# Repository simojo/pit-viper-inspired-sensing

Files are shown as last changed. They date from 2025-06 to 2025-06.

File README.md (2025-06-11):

# Pit Viper-Inspired Integration of Thermal and Visual Sensing

This project contains the source code, design files, and run data for our
project that integrates thermal and visual sensing.

[Project Video](https://www.youtube.com/watch?v=YbGg3W7sRKU)

```
Authors (all credited equally):

Julianne Attai         <julianne.attai at colorado dot edu>
Simon Jones            <simon.jones-1 at colorado dot edu>
Tanmay Dharmaji Mhatre <tanmay.mhatre at colorado dot edu>
Saravana Kumar Prakash <sako6004 at colorado dot edu>
```

## Directory Structure

```sh
.
├── apriltag . . . . . . . . . apriltag source code
├── data . . . . . . . . . . . cad models and data from runs
│  ├── mechanical-data
│  └── runs
├── sanity-examples  . . . . . minimal working examples for our own sanity
│  ├── thermal-sensing
│  ├── camera_test.py
│  ├── motor_test.py
│  ├── picam2_array_test.py
│  └── picamera-test.py
├── src  . . . . . . . . . . . main source code
│  └── main.py
├── README.md
├── requirements.txt . . . . . libraries used in source code
└── setup.sh . . . . . . . . . setup script for RPi4
```

## How to run

To set up this project, first source `setup.sh` on a Raspberry Pi 4 image running
Bookworm or later.

```sh
. setup.sh
```

This will take care of initializing the venv and installing system packages.

Next, install the packages from `requirements.txt`:

```sh
pip install -r requirements.txt
```

Finally, run the main source code, using `-d` for debug mode, and `-ld` for data
logging mode. You can optionally disable either thermal or visual sensing by
using `--visual-only` and `--thermal-only` respectively. By default, both
sensing modalities are in use.

```sh
python3 src/main.py [-d] [-ld] [--visual-only] [--thermal-only]
```

## For reference

* https://www.circuitstoday.com/arduino-nano-tutorial-pinout-schematics
* https://learn.sparkfun.com/tutorials/tb6612fng-hookup-guide/all#hardware-setup

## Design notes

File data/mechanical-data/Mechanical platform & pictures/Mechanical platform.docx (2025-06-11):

Mechanical platform

The authors’ main goal from a mechanical perspective is to make room for all the electronic parts, including the Raspberry Pi, breadboard, camera, thermal sensors, motors, batteries, wiring, etc. To ensure that motors and sensors don't wobble while operating, the mechanical housing should also have specific design elements.

1)Concept generation

Our authors developed the design below during preliminary conversations, with the electronic components on the top and bottom base plates intended to be made of acrylic. The writers have also decided to use the trike's motorized front wheels and driven rear wheels for propulsion. For the robot's turning, the differential drive concept was selected.

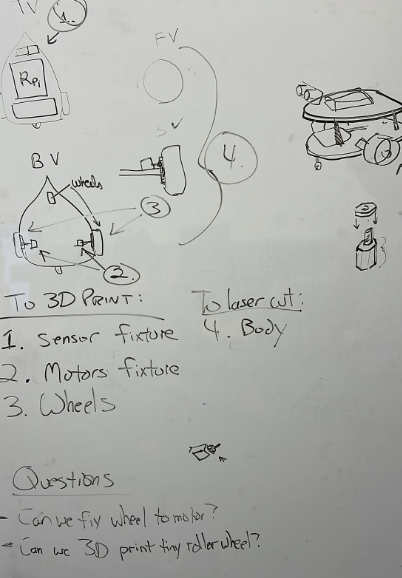
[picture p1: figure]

2) Design iterations

i) Initial design: A CAD model that replicated the idea was created by designers. A table-like framework was all that was originally intended to house sensors at the top and other electrical components that would be packaged below the base.

2) Final design: A snake-head structure was created following multiple forums, as seen below. There is adequate room for sensors at the top that resemble the snake's eyes thanks to this snake-inspired design. Both housings' front sections are sufficiently shaped to avoid obstructing the sensor's field of vision.

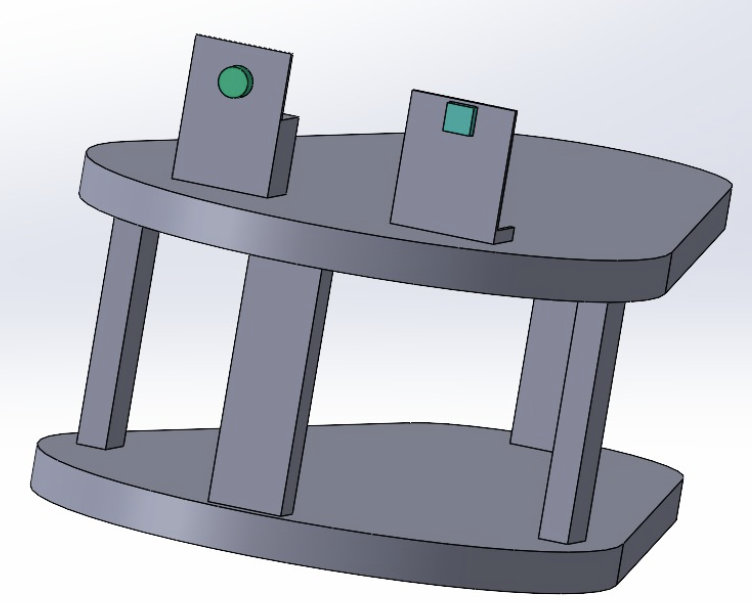
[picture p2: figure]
A drawing of a table
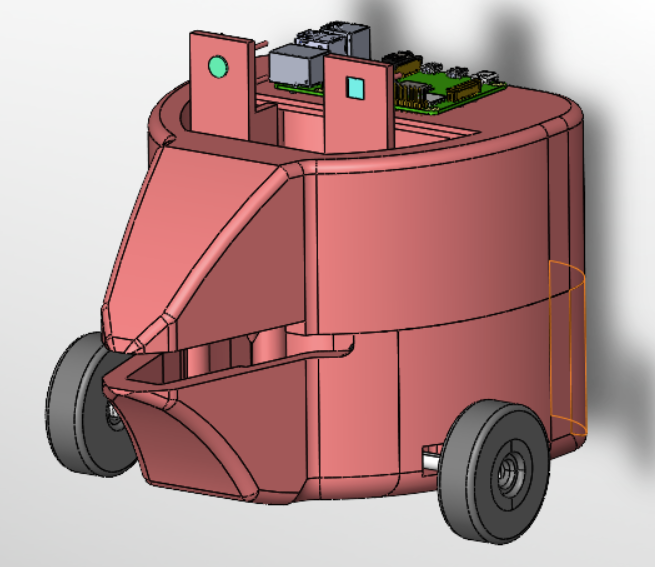
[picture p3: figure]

Final design

Initial design

Manufacturing failures

The body and wheels were created by the writers using 3D printing technology. The outputs were not what was anticipated because of the design's robustness. The body designs were divided into multiple pieces and intended to be joined using the projections and holes method, based on the lessons learned about designing quickly for manufacturing (3D printing). Following a difficult post-printing procedure that resulted in assembly features breaking, the bodies were assembled using Velcro and glue. Velcro is specifically employed to make assembly/disassembly feasible in the event that electronics need to be updated.

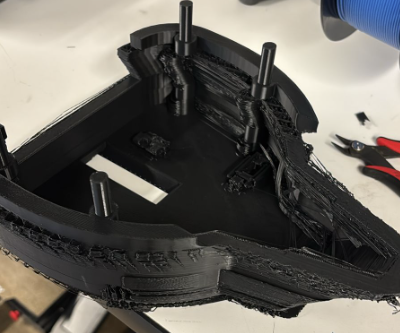
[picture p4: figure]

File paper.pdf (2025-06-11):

# Pit Viper-Inspired Integration of Infrared and Visual Sensing

Julianne Attai∗

, Simon Jones†

, Tanmay Dharmaji Mhatre‡

, Saravana Kumar Prakash§
∗†Robotics Program, University of Colorado Boulder, Boulder, CO, USA ‡§Paul M. Rady Department of Mechanical Engineering, University of Colorado Boulder, Boulder, CO, USA
∗

julianne.attai@colorado.edu, †

simon.jones-1@colorado.edu, ‡

tanmay.mhatre@colorado.edu, § sako6004@colorado.edu

Abstract—Pit vipers leverage both infrared (IR) and vision for hunting. Each sensing modality can function independently but operate more effectively together, motivating the hypothesis that combining and IR and vision will out-perform singlesensing approaches in navigation and prey detection. To test this underlying hypothesis, a robot with dual-sensing capabilities has been designed to integrate information from a Adafruit MLX90640 IR Thermal Camera Breakout - 55 Degree and Raspberry Pi Camera Module 2 and steer the robot accurately towards a target. Thermal sensing performed the best, having the shortest time to reach (TTR) to the target, and the lowest heading angle variance across trials. Visual sensing performed the worst, having the largest variance in heading angles and the longest TTR. Dual sensing had the least variance in heading angle, but did not outperform thermal sensing alone in terms of TTR. The results of this project highlight the integral role IR sensing plays in target tracking accurately during predator-prey interactions.
Index Terms—Infrared Vision, Camera Vision, Pit Vipers.
I. INTRODUCTION
Pit Vipers are ferocious predators that are able to accurately strike their prey, even in darkness. These animals leverage infrared vision, through pit organs rich in heat-sensitive nerve fibers, while hunting to track the radiation emitted by their target. They also use many visual cues during hunting, particularly for navigation and landmark recognition. Both sensing modalities are integral in achieving high predatory performance.
In this report, two sensing modalities, infrared and visual sensing, are integrated to navigate towards a target or prey. In order to implement this, the authors built a mechanical platform that can be steered through differential drive. A Raspberry Pi Camera Module 2 is used to collect visual data, while a Adafruit MLX90640 IR Thermal Camera Breakout
- 55 Degree is used to collect thermal data. This data is processed to identify the distance from target and the desired heading angle to steer towards the target.
In this report, the main contributions of the project are outlined as follows:
- Designing a snake-inspired mechanical platform for IR and vision based steering
- Developing an algorithm to process thermal images and identify the centroid of the heat map
- Developing an algorithm to process visual images and identify the centroid of the target and its’ distance relative to the robot

II. BACKGROUND

A. Infrared (IR) vision in rattlesnakes

Rattlesnakes can accurately strike prey, even in darkness by sensing infrared radiation emitted by their prey [1] . Pit organs act as the “eyes” of the rattlesnake, which are rich in heat-sensitive nerve fibers that connect to the brain [2]. These pit organs are used to identify prey, and allow the animal to track and locate thermal targets, even when blindfolded [3]. While pit organs are important in finding prey, it was found that rattlesnakes do not rely on their pit organs during simple navigation. A study by Schraft and Clark found that snakes primarily use visual cues to orient themselves (e.g. identifying bushes and structures) and navigate in the darkness [4], rather than infrared cues. Rattlesnakes in general, are believed to only use infrared sensing in certain contexts, particularly locating prey while hunting [4].

B. Integration of IR and vision sensing

In absence of both visual and infrared sensing, predatory performance diminishes significantly. However, it has been shown that these sensory systems can still achieve high performance (75%) when either one of eye vision or pit organs were occluded [5], [6] . The results of these studies imply that rattlesnakes can effectively switch sensing modalities and still achieve high predatory performance, but ultimately integrate both modalities of sensing for optimal navigation and hunting.

III. HYPOTHESES

The main biological principle the authors will be exploring in this paper is the integration of dual perception and sensing in rattlesnakes which is used to achieve high performance during predatory hunting. This is further detailed in the following three cases below:

1) Navigation and prey/target detection using two sensing modalities will achieve higher performance than just one modality
2) It is still possible to navigate and locate a prey with just IR sensing (but performance will be reduced)
3) It is still possible to navigate and locate a prey with just vision (but performance will be reduced)

IV. METHODS
In order to test the following hypotheses, the authors designed and built a robotic pit viper. The robotic pit viber was designed to enable steering through differential drive. The control logic is programmed onto a Raspberry Pi 4 which was powered externally (the robot remained tethered during the experiments).
A. Mechanical Platform
The authors’ main goal from a mechanical perspective is to make room for all the electronic parts, including the Raspberry Pi, breadboard, camera, thermal sensors, motors, batteries, wiring, etc. To ensure that motors and sensors don’t wobble while operating, the mechanical housing should also have specific design elements.
1) Concept generation: Our authors developed the design below during preliminary conversations, with the electronic components on the top and bottom base plates intended to be made of acrylic. The authors have also decided to use the trike’s motorized front wheels and driven rear wheels for propulsion. For the robot’s turning, the differential drive concept was selected.
2) Design iterations: The initial design, shown in Figure 1 was CAD model that replicated the idea was created by designers. A table-like framework was all that was originally intended to house sensors at the top and other electrical components that would be packaged below the base.
The final design, in Figure 2 is a snake-head structure was created following multiple forums, as seen below. There is adequate room for sensors at the top that resemble the snake’s eyes thanks to this snake-inspired design. Both housings’ front sections are sufficiently shaped to avoid obstructing the sensor’s field of vision.

Fig. 1: Initial Design

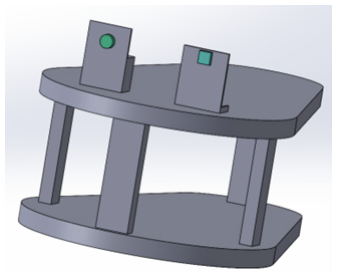
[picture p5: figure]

3) Manufacturing failures: The body and wheels were created by the writers using 3D printing technology. The outputs were not what was anticipated because of the design’s robustness. The body designs were divided into multiple pieces and intended to be joined using the projections and holes method, based on the lessons learned about designing quickly for manufacturing (3D printing). Following a difficult postprinting procedure that resulted in assembly features breaking,

Fig. 2: Final Design

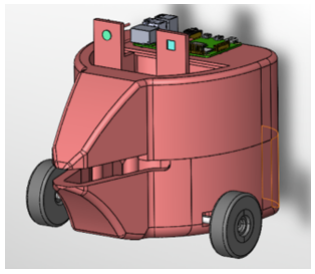
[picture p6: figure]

the bodies were assembled using Velcro and glue. Velcro is specifically employed to make assembly/disassembly feasible in the event that electronics need to be updated.

Fig. 3: Manufacturing failures

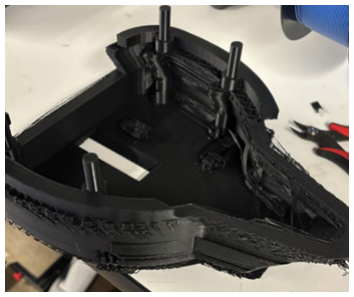
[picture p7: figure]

B. Sensing modalities
1) Vision: For visual sensing, the authors used a Raspberry Pi Camera Module 2 to gather visual images of the environment. As a image recognition module would’ve been beyond the timing constraints of the class, April Tags 1 were used as a low power proxy for object recognition, that provides useful information about the robot’s location relative the April Tag. For each image, it first checks if an April Tag was detected. If so, the pixel coordinates of the centroid of the April Tag is calculated. From there the heading angle and distance to the target are calculated with the following equations:

Distance from target =

tag size cm × frame width pixel tag size pixel

Heading angle to target = delta y × angle per pixel

The tag size cm is the true size of the April Tag in cm. During testing, April Tags of 3 cm were used.

1https://april.eecs.umich.edu/software/apriltag

Fig. 4: Sample of visual data - annotated

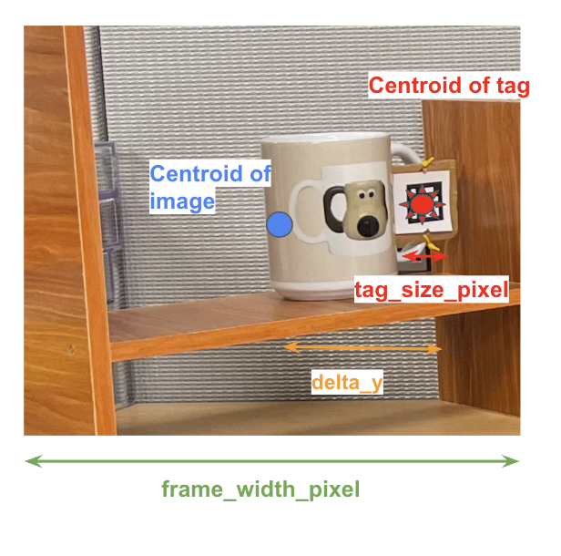
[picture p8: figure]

Fig. 5: April tags

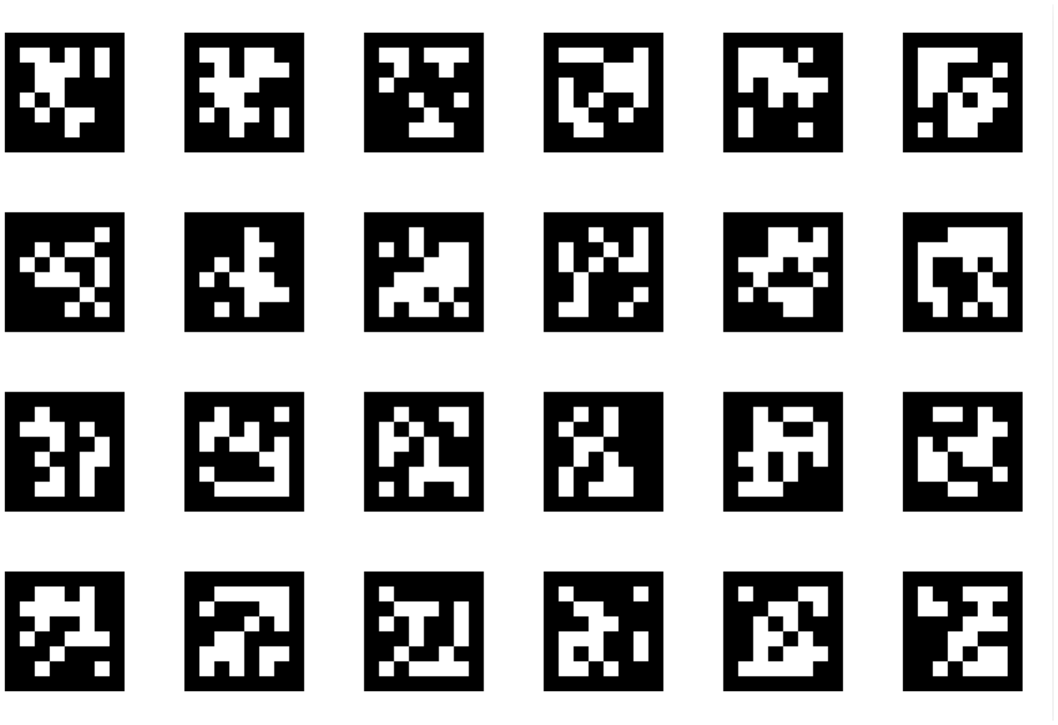
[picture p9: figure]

2) Thermal: For thermal sensing the Adafruit MLX90640 IR Thermal Camera Breakout - 55 Degree provides a thermal image as shown in Figure 6.
For each thermal image, a binary mask is applied to identify areas above the temperature threshold (>35). The
center_of_mass function from scipy.ndimage is then
used to calculate the thermal centroid.
The heading angle is calculated with the same formula used for visual sensing. Note that delta y is calculated as the pixel distance in y from the center of the image to the thermal centroid.

Fig. 6: Sample of thermal data

3) Integration: To integrate these two sensing modalities, the desired heading angles were averaged from each sensing modality. The authors note this is a rudimentary implementation of sensing integration, and further implementations could consider uncertainty of data measurements to weigh the heading angles accordingly.
To steer the robot, the authors implemented a simple bangbang controller: when the desired heading angle is small (|θ| < 1

◦
), the robot goes straight; otherwise the robot turns towards the target until heading angle is small.
V. TESTING SETUP

To perform the experiments, the authors tethered the robotic platform to a power supply, monitor, and keyboard on a test bench. Figure 7 shows the configuration for all experiments, with the robot and target being separated by approximately 1m.

Fig. 7: Experimental test bench. On the left is the thermal source with an April Tag attached. On the right is the robotic platform before starting. The monitor displays the feedback from both thermal and visual sensors.

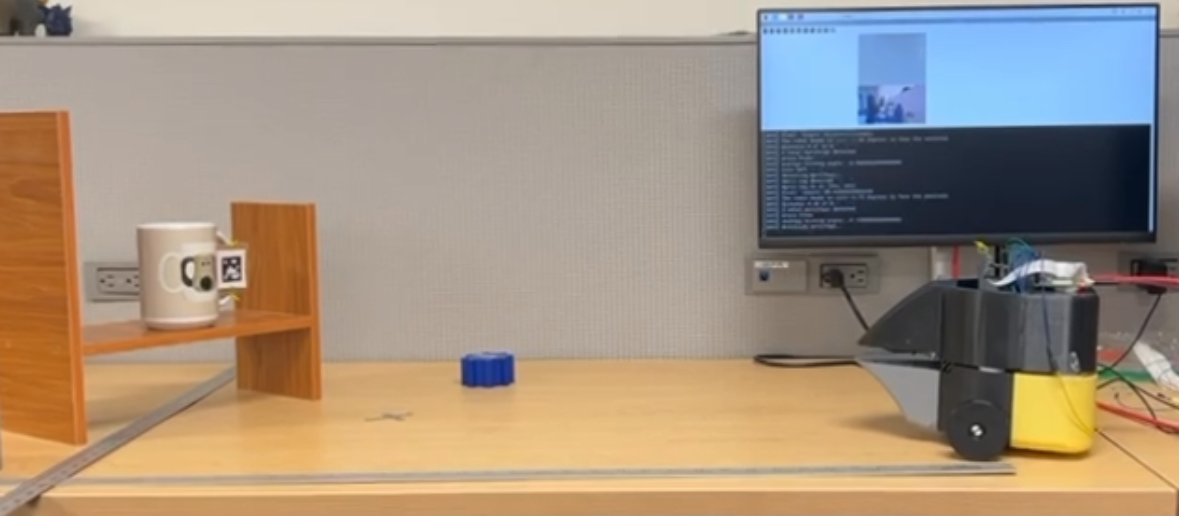
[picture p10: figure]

The authors performed five trials for three different experimental configurations: (1) visual sensing only; (2) thermal sensing only; (3) both visual and thermal sensing. During each trial, the calculated “heading angle” from the two sensing modalities were recorded, along with the timestamp associated with each data point.
Accuracy during a trial was evaluated by the time to reach (TTR) the goal (denoted by a taped ‘X’ on the test bench) and the variance of the heading angle over time. A shorter TTR would suggest higher accuracy, as well as low variance of the heading angle during a trial.

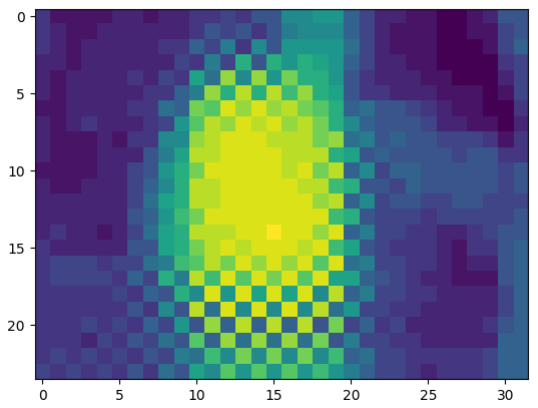
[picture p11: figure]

VI. RESULTS

High overall accuracy was observed when integrating thermal and visual sensing as opposed to using either exclusively. Because both thermal and visual images were being captured regardless of trial type, the frame rate of all trials was limited to ≈ 2Hz.
Visual sensing trials, seen in Figure 8, were observed to have the longest TTR and the largest heading angle variance for each trial. Each trial varied by approximately 20◦ on average between maximum and minimum heading angle values.

Thermal sensing trials, seen in Figure 9, had the shortest TTR and the lowest heading angle variance for each trial, varying approximately 15◦ per trial. Although the resolution of the thermal sensor was lower than that of the visual, it permitted the system to remain more consistent with respect to its heading angle.
Dual sensing trials, shown in Figure 10, showed the least variance in heading angle, but not as short of a TTR as thermal sensing alone. When integrating both sensing modalities, an obvious calibration error was observed in that both sensors read different initial heading angles, even though they were oriented identically.

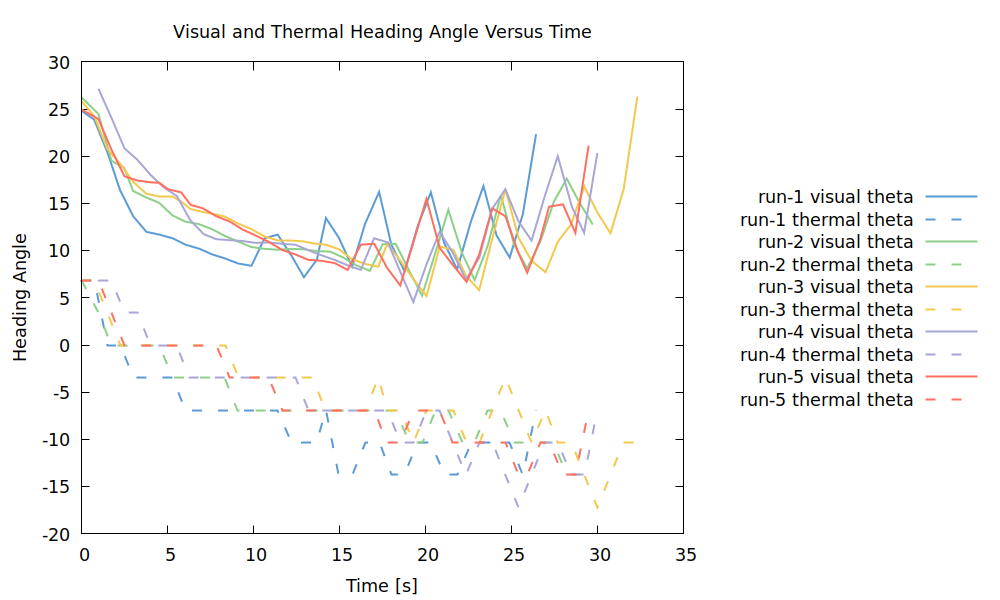
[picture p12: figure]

Fig. 8: Results for visual sensing trials.

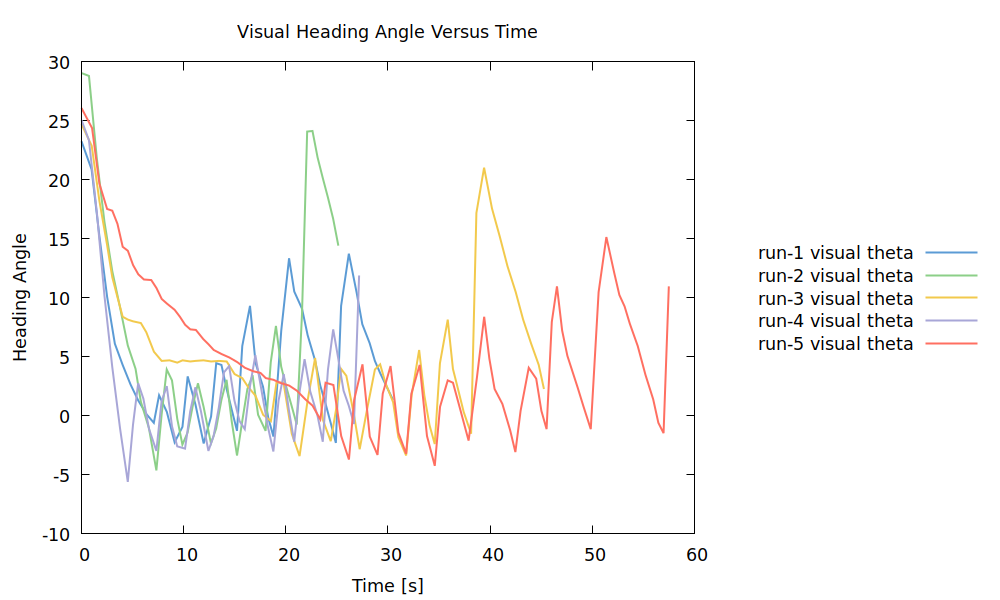
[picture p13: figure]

Fig. 9: Results for thermal sensing trials.

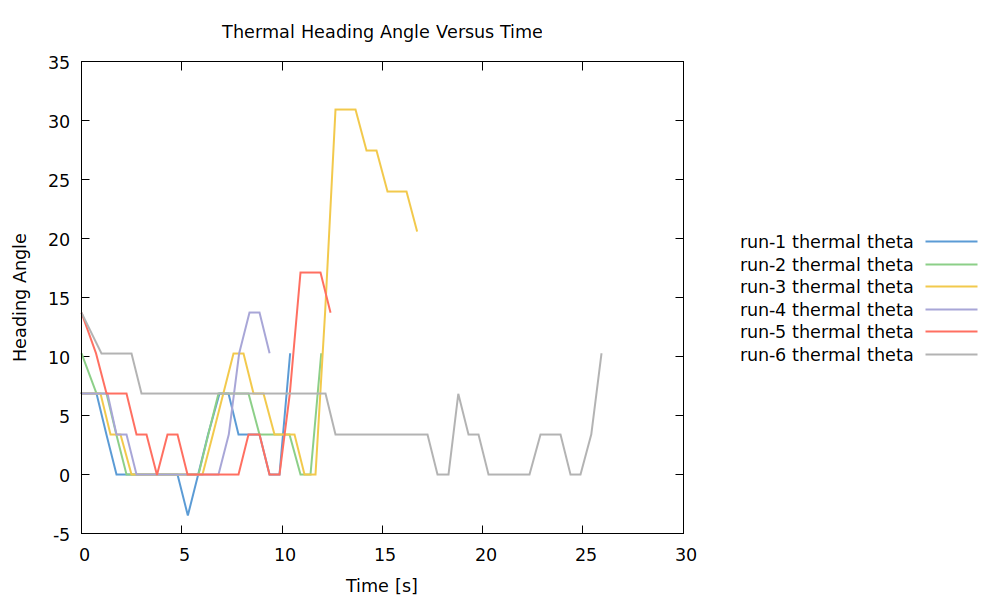
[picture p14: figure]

VII. DISCUSSION AND FUTURE WORK

Thermal sensing was more accurate and quick to detect and steer towards a target, which is similar to how pit vipers rely primarily on IR sensing during hunting to accurately strike prey. Dual sensing performed worse than IR alone with respect to TTR, which was contrary to the initial hypothesis (that dual-sensing would outperform single sensing modalities); however, dual sensing outperformed both individual modes of sensing with respect to heading angle variance. The observed increase

Fig. 10: Results for dual sensing trials.

in stability can be attributed to the steering algorithm averaging the thermal and visual centroids. The longer TTR for dual sensing could be a limitation of how the sensor data was integrated (averaging angles). A more sophisticated way to fuse information (e.g. weighing data by uncertainty) could potentially yield more accurate results.
In this project, the authors developed a snake-inspired mechanical platform to IR and vision based steering and developed an algorithm to process thermal and visual images and identifying the desired heading angle to steer towards. The results support that IR sensing plays an integral role in prey tracking during hunting.

REFERENCES

[1] T. De Cock Buning, “Thermal sensitivity as a specialization for prey capture and feeding in snakes,” vol. 23, no. 2, pp. 363–375.
[2] E. A. Newman and P. H. Hartline, “The infrared ”vision” of snakes,” vol. 246, no. 3, pp. 116–127. Publisher: Scientific American, a division of Nature America, Inc.
[3] J. U. Van Dyke and M. S. Grace, “The role of thermal contrast in infraredbased defensive targeting by the copperhead, Agkistrodon contortrix,” vol. 79, no. 5, pp. 993–999.
[4] H. A. Schraft and R. W. Clark, “Sensory basis of navigation in snakes: the relative importance of eyes and pit organs,” vol. 147, pp. 77–82.
[5] J. E. Haverly and K. V. Kardong, “Sensory deprivation effects on the predatory behavior of the rattlesnake, crotalus viridis oreganus,” vol. 1996, no. 2, pp. 419–428. Publisher: [American Society of Ichthyologists and Herpetologists (ASIH), Allen Press].
[6] Q. Chen, H. Deng, S. E. Brauth, L. Ding, and Y. Tang, “Reduced performance of prey targeting in pit vipers with contralaterally occluded infrared and visual senses,” vol. 7, no. 5, p. e34989. Publisher: Public Library of Science.

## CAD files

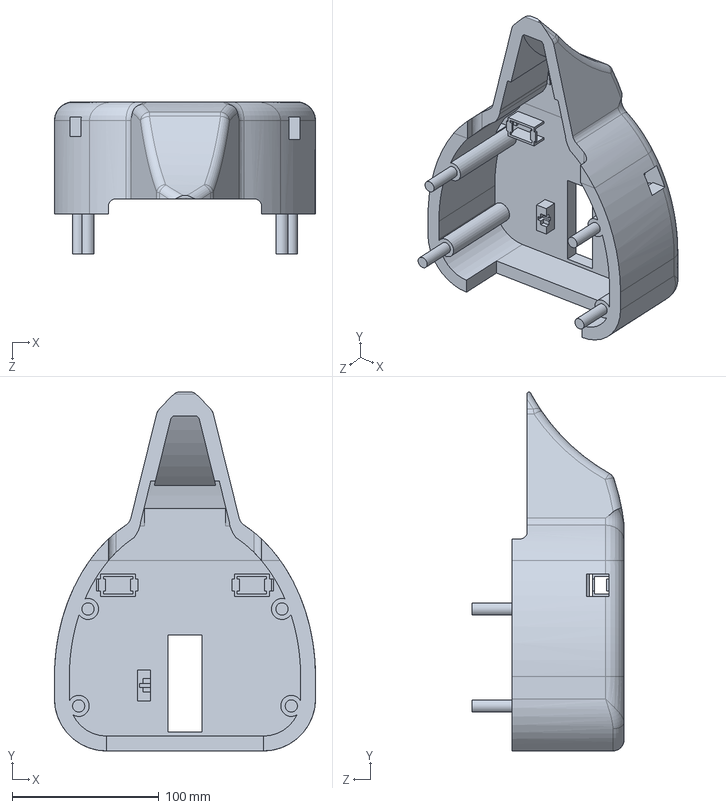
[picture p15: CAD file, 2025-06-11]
data/mechanical-data/ROBOT ASSEMBLY WITH CAD/SH01-01 SNAKE HEAD LOWER BODY.SLDPRT
177.8 x 244.4 x 103.6 mm

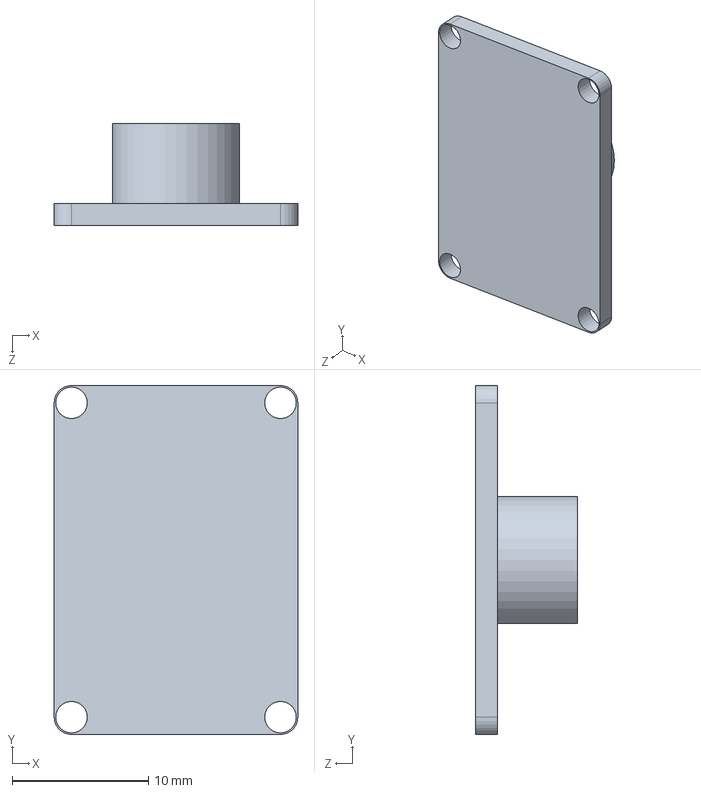
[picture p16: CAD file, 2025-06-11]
data/mechanical-data/ROBOT ASSEMBLY WITH CAD/SH04-02 THERMAL SENSOR.SLDPRT
17.9 x 25.6 x 7.51 mm

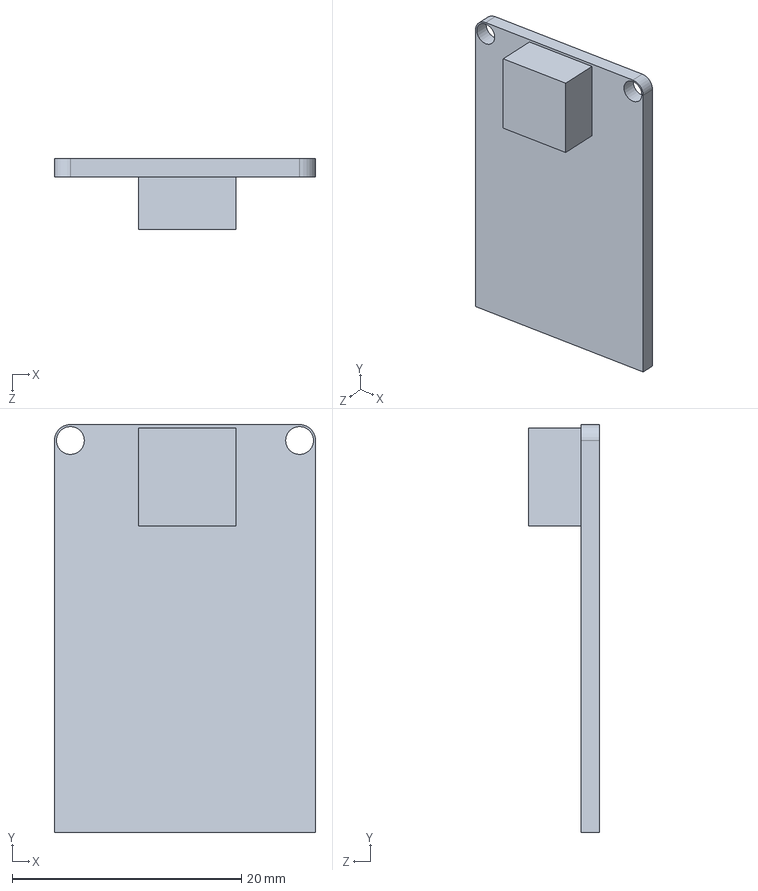
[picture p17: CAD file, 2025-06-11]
data/mechanical-data/ROBOT ASSEMBLY WITH CAD/SH04-01 CAMERA SENSOR.SLDPRT
22.8 x 35.6 x 6.20 mm

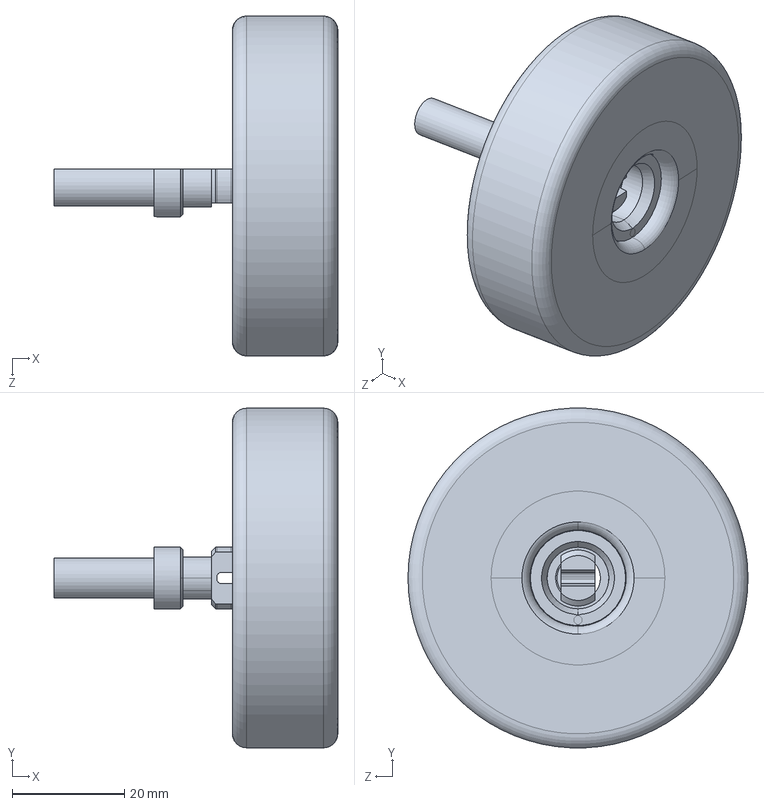
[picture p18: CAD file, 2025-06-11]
data/mechanical-data/ROBOT ASSEMBLY WITH CAD/FRONT WHEEL SNAP FIT ROD + SNAP FIT WHEEL.SLDPRT
50.6 x 60.6 x 60.6 mm

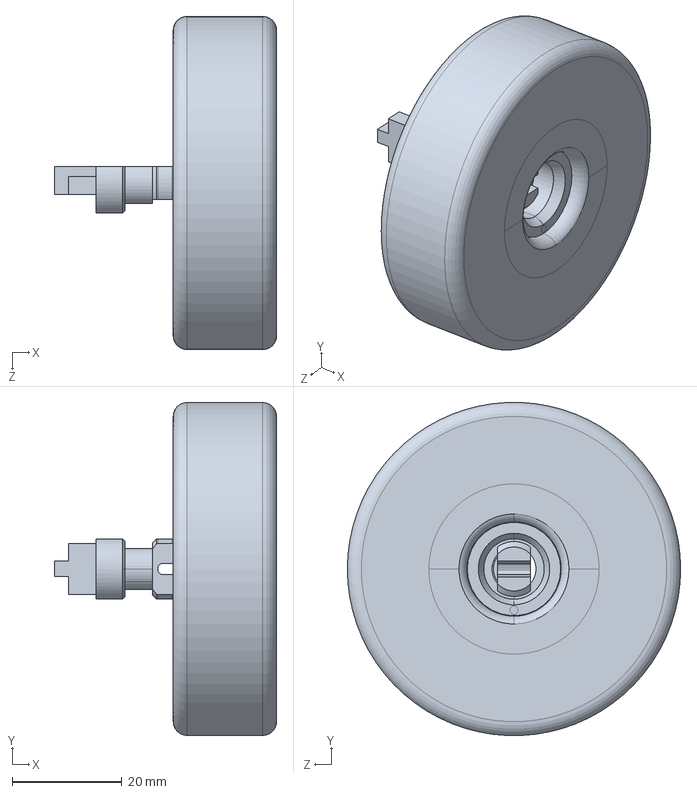
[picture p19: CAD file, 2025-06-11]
data/mechanical-data/ROBOT ASSEMBLY WITH CAD/BACK WHEEL SNAP FIT ROD + SNAP FIT WHEEL.SLDPRT
40.5 x 60.6 x 60.6 mm

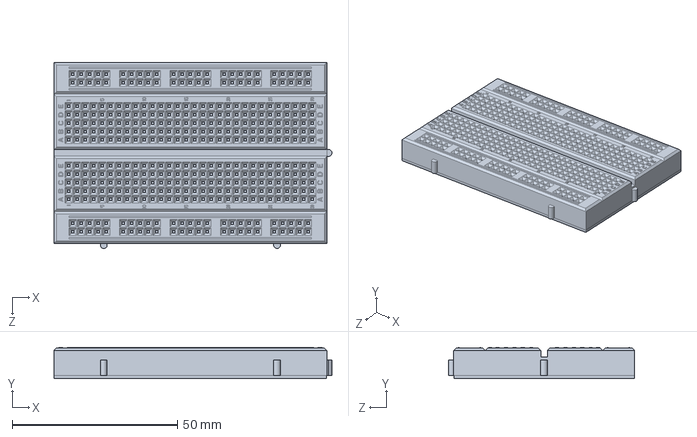
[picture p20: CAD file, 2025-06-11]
data/mechanical-data/ROBOT ASSEMBLY WITH CAD/SH03-02 BREADBOARD.SLDPRT
84.1 x 9.50 x 56.3 mm

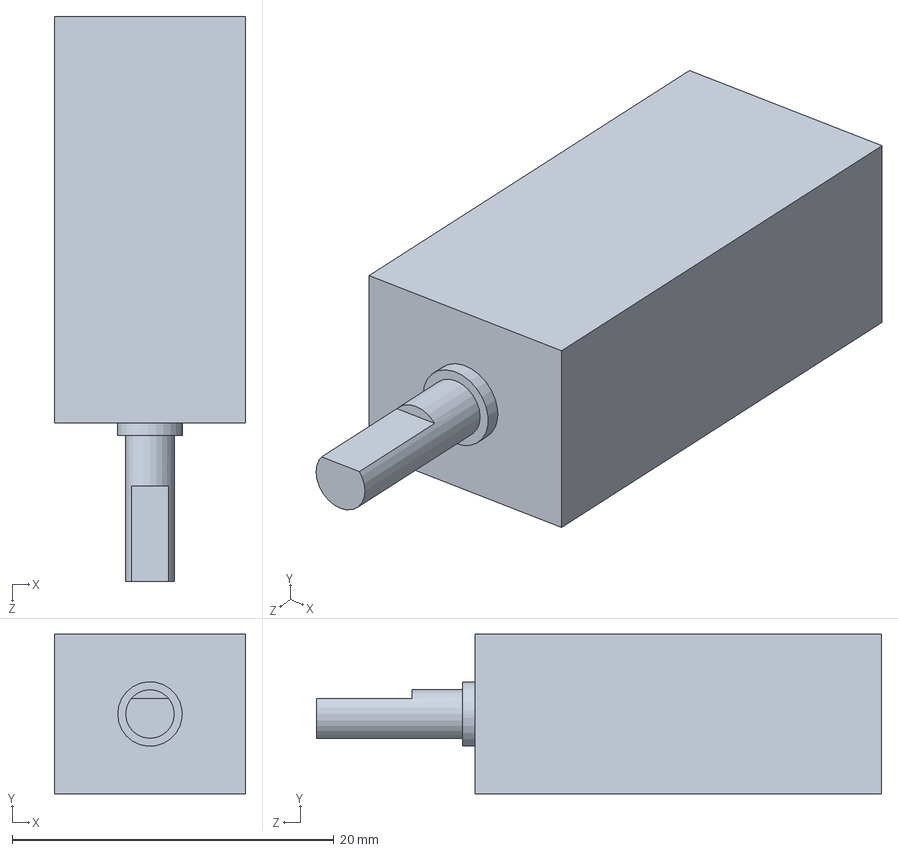
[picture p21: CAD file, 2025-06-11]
data/mechanical-data/ROBOT ASSEMBLY WITH CAD/SH03-01 MOTOR.SLDPRT
11.9 x 9.92 x 35.2 mm

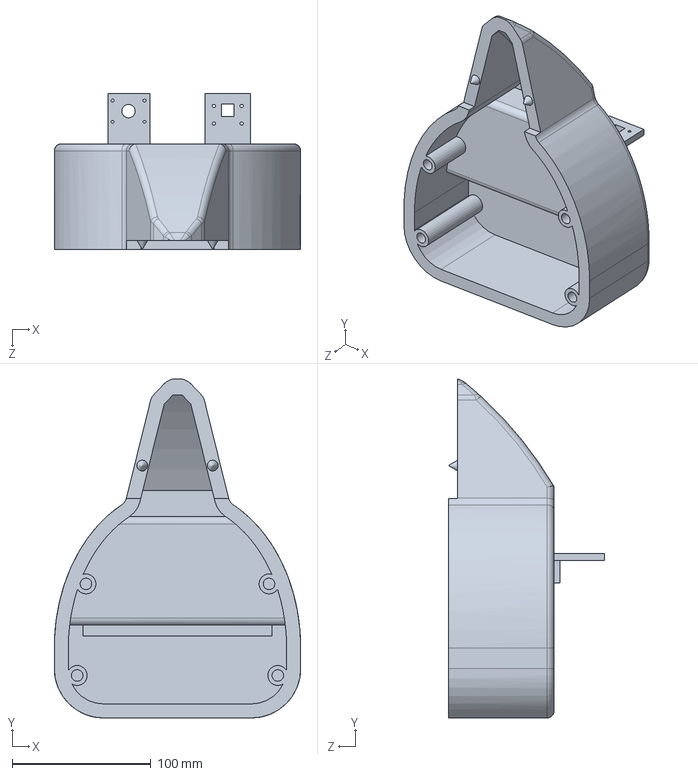
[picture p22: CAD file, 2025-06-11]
data/mechanical-data/ROBOT ASSEMBLY WITH CAD/SH01-02 SNAKE HEAD UPPER BODY.SLDPRT
177.8 x 244.6 x 112.5 mm

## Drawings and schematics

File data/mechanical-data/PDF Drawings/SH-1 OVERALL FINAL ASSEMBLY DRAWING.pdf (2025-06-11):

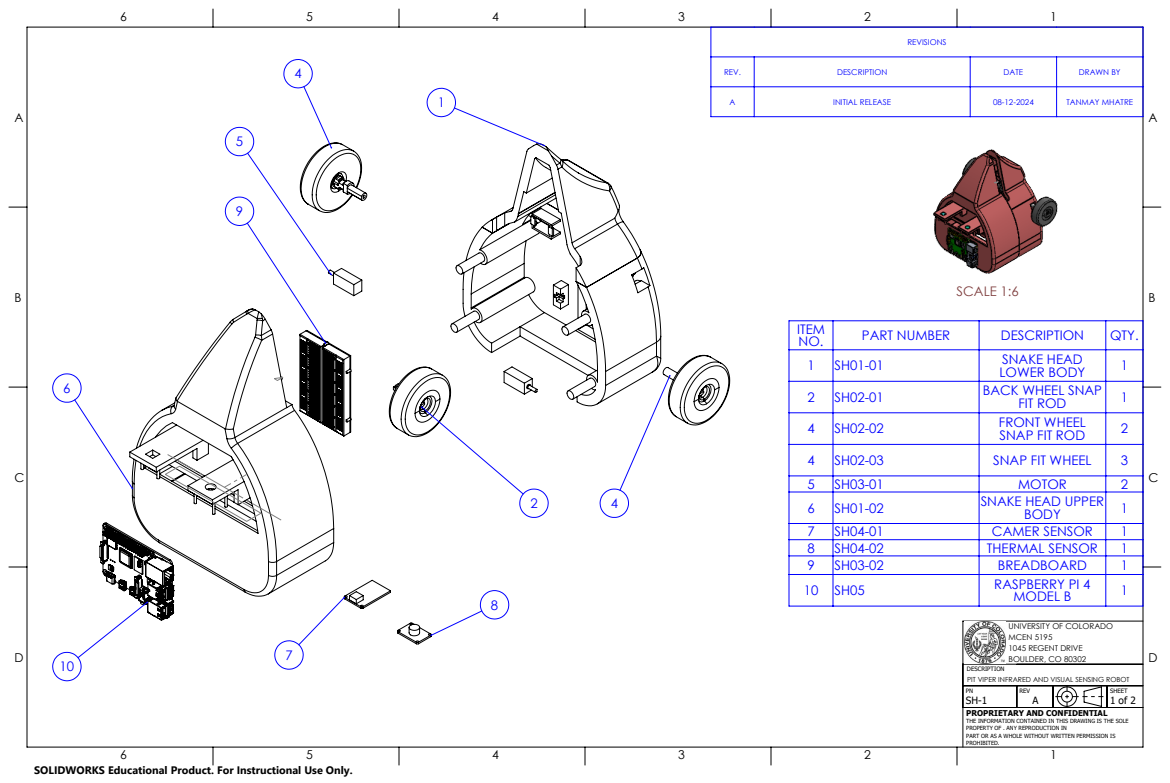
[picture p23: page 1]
SCALE 1:6

REVISIONS

REV. | DESCRIPTION | DATE | DRAWN BY

A | INITIAL RELEASE | 08-12-2024 | TANMAY MHATRE

ITEM NO. | PART NUMBER | DESCRIPTION | QTY.
1 | SH01-01 | SNAKE HEAD LOWER BODY | 1
2 | SH02-01 | BACK WHEEL SNAP FIT ROD | 1
4 | SH02-02 | FRONT WHEEL SNAP FIT ROD | 2

4 | SH02-03 | SNAP FIT WHEEL | 3
5 | SH03-01 | MOTOR | 2
6 | SH01-02 | SNAKE HEAD UPPER BODY | 1
7 | SH04-01 | CAMER SENSOR | 1
8 | SH04-02 | THERMAL SENSOR | 1
9 | SH03-02 | BREADBOARD | 1
10 | SH05 | RASPBERRY PI 4 MODEL B | 1

UNIVERSITY OF COLORADO
MCEN 5195
1045 REGENT DRIVE
BOULDER, CO 80302

DESCRIPTION
PIT VIPER INFRARED AND VISUAL SENSING ROBOT
PROPRIETARY AND CONFIDENTIAL
THE INFORMATION CONTAINED IN THIS DRAWING IS THE SOLE
PROPERTY OF . ANY REPRODUCTION IN
PART OR AS A WHOLE WITHOUT WRITTEN PERMISSION IS
PROHIBITED.

SOLIDWORKS Educational Product. For Instructional Use Only.

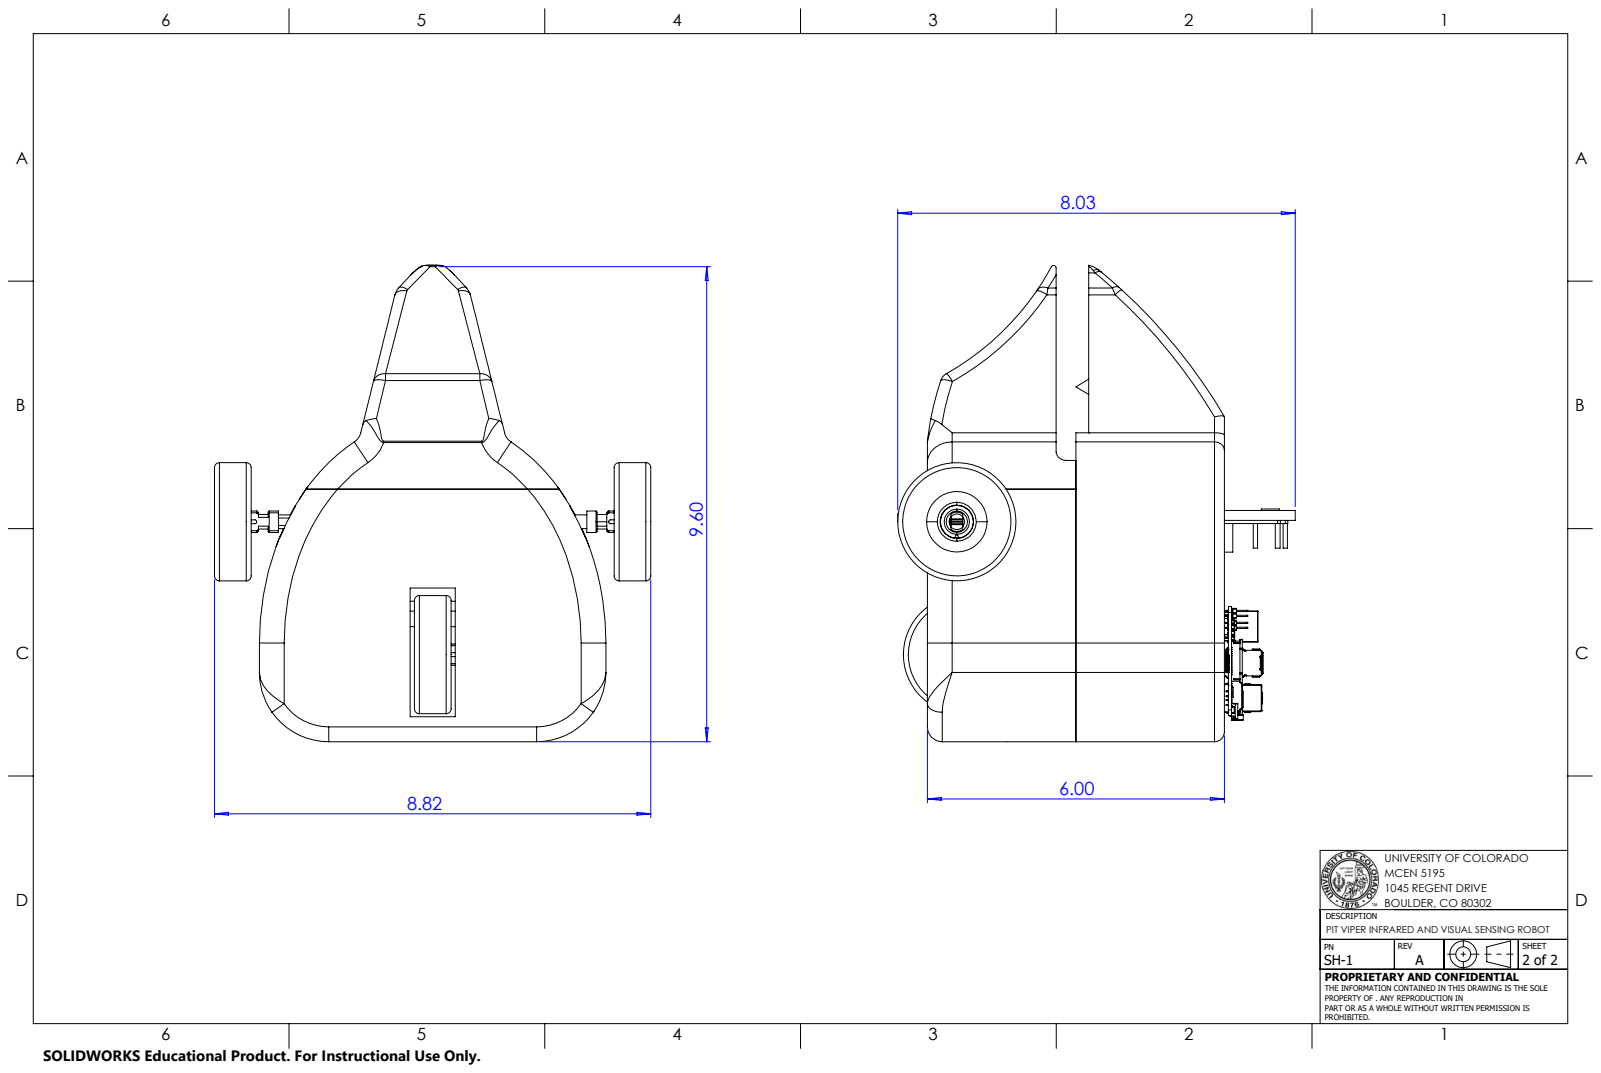
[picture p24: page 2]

UNIVERSITY OF COLORADO
MCEN 5195
1045 REGENT DRIVE
BOULDER, CO 80302

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

SOLIDWORKS Educational Product. For Instructional Use Only.

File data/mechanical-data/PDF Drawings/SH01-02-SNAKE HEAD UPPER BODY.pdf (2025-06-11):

## REVISIONS

ZONE | REV. | DESCRIPTION | DATE | DRAWN BY

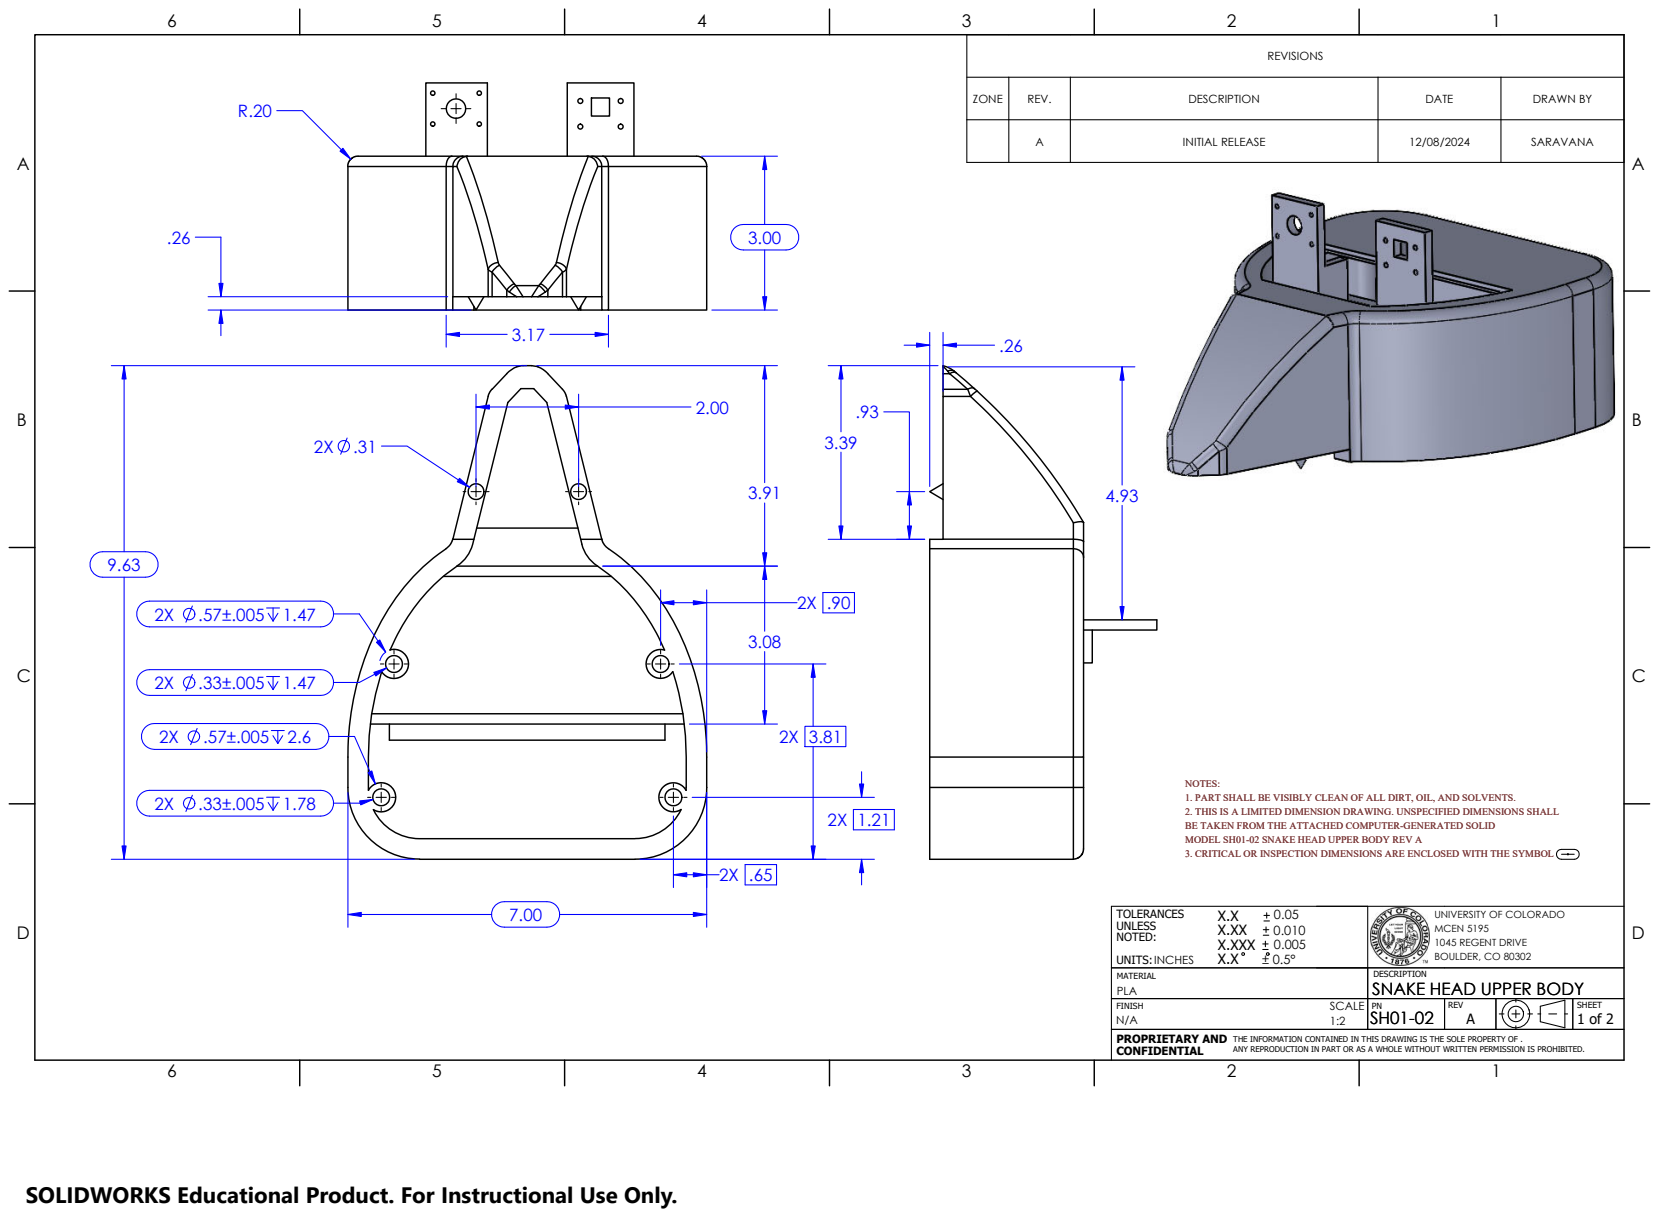
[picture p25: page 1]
PROPRIETARY AND CONFIDENTIAL

A | INITIAL RELEASE | 12/08/2024 | SARAVANA

NOTES:
1. PART SHALL BE VISIBLY CLEAN OF ALL DIRT, OIL, AND SOLVENTS.
2. THIS IS A LIMITED DIMENSION DRAWING. UNSPECIFIED DIMENSIONS SHALL
BE TAKEN FROM THE ATTACHED COMPUTER-GENERATED SOLID
MODEL SH01-02 SNAKE HEAD UPPER BODY REV A
3. CRITICAL OR INSPECTION DIMENSIONS ARE ENCLOSED WITH THE SYMBOL

TOLERANCES X.X 0.05 UNLESS X.XX 0.010 NOTED: X.XXX 0.005 UNITS: INCHES X.X ± 0.5° | UNIVERSITY OF COLORADO MCEN 5195 1045 REGENT DRIVE BOULDER, CO 80302

MATERIAL PLA | DESCRIPTION SNAKE HEAD UPPER BODY SNAKE HEAD UPPER BODY
SCALE FINISH N/A 1:2 | PN SH01-02 SH01-02 | REV A | SHEET 1 of 2

THE INFORMATION CONTAINED IN THIS DRAWING IS THE SOLE PROPERTY OF .
ANY REPRODUCTION IN PART OR AS A WHOLE WITHOUT WRITTEN PERMISSION IS PROHIBITED.

SOLIDWORKS Educational Product. For Instructional Use Only.

4

A

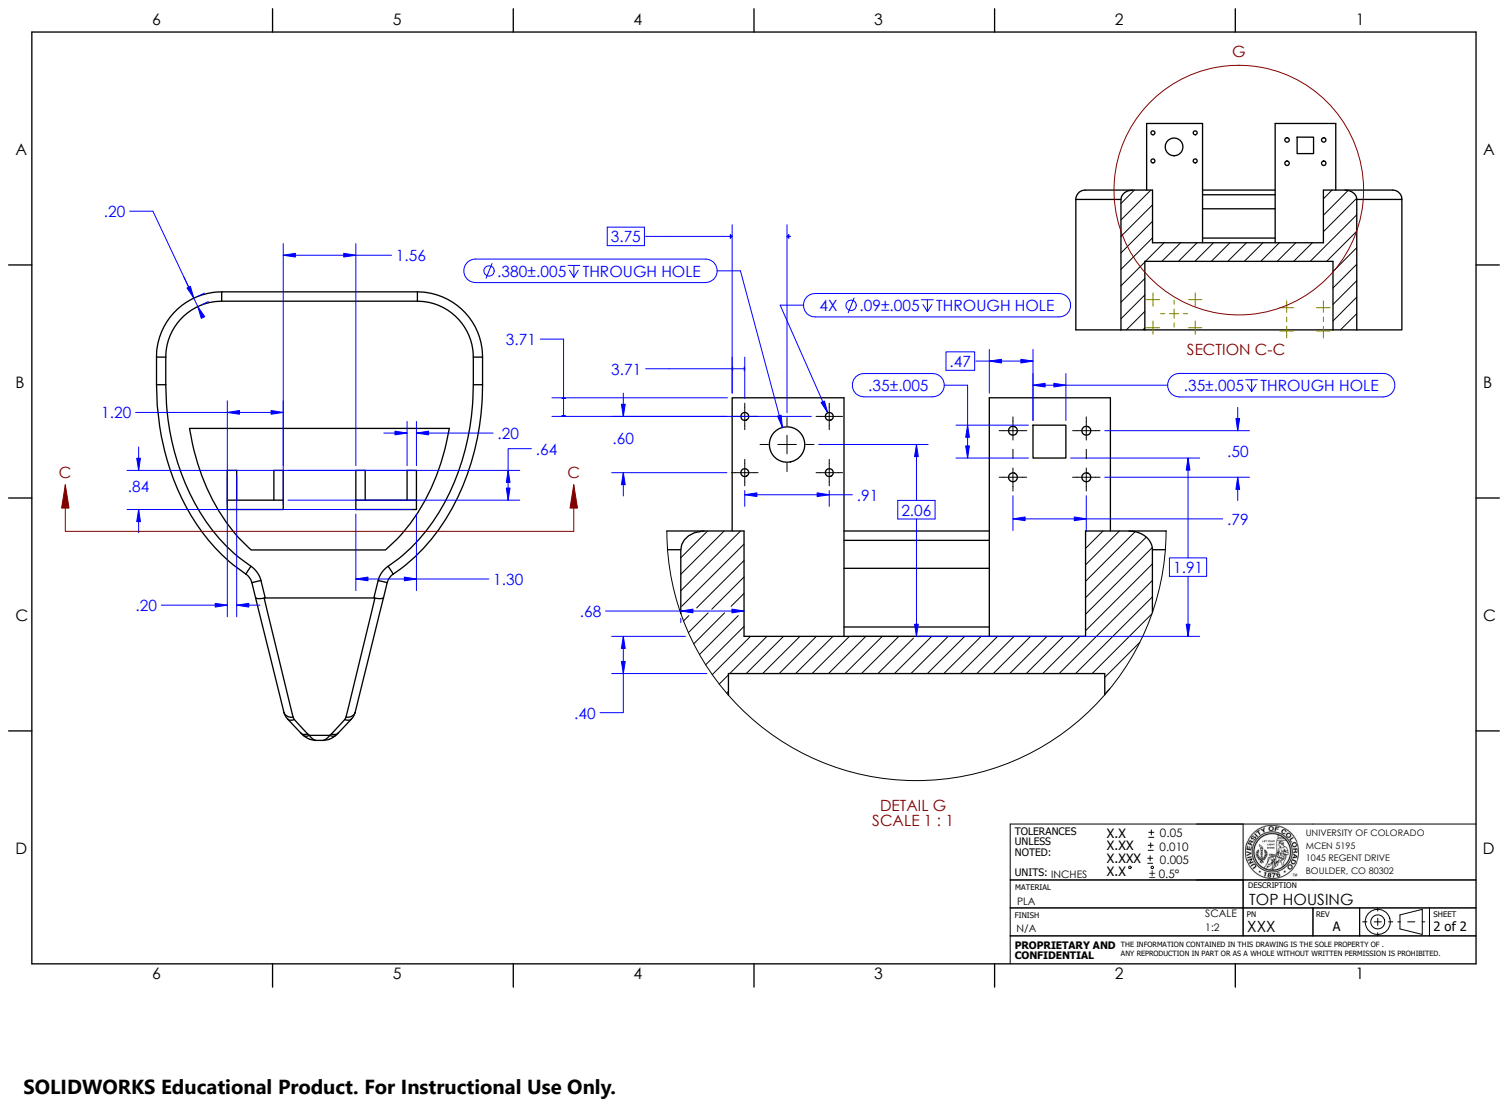
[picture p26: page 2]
PROPRIETARY AND CONFIDENTIAL; DETAIL G SCALE 1 : 1; THROUGH HOLE; SECTION C-C

TOLERANCES X.X 0.05 UNLESS X.XX 0.010 NOTED: X.XXX 0.005 UNITS: X.X ± 0.5° | UNIVERSITY OF COLORADO MCEN 5195 1045 REGENT DRIVE BOULDER, CO 80302 INCHES

MATERIAL PLA | DESCRIPTION TOP HOUSING

SCALE FINISH N/A 1:2 | PN XXX | REV A | SHEET 2 of 2

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

SOLIDWORKS Educational Product. For Instructional Use Only.

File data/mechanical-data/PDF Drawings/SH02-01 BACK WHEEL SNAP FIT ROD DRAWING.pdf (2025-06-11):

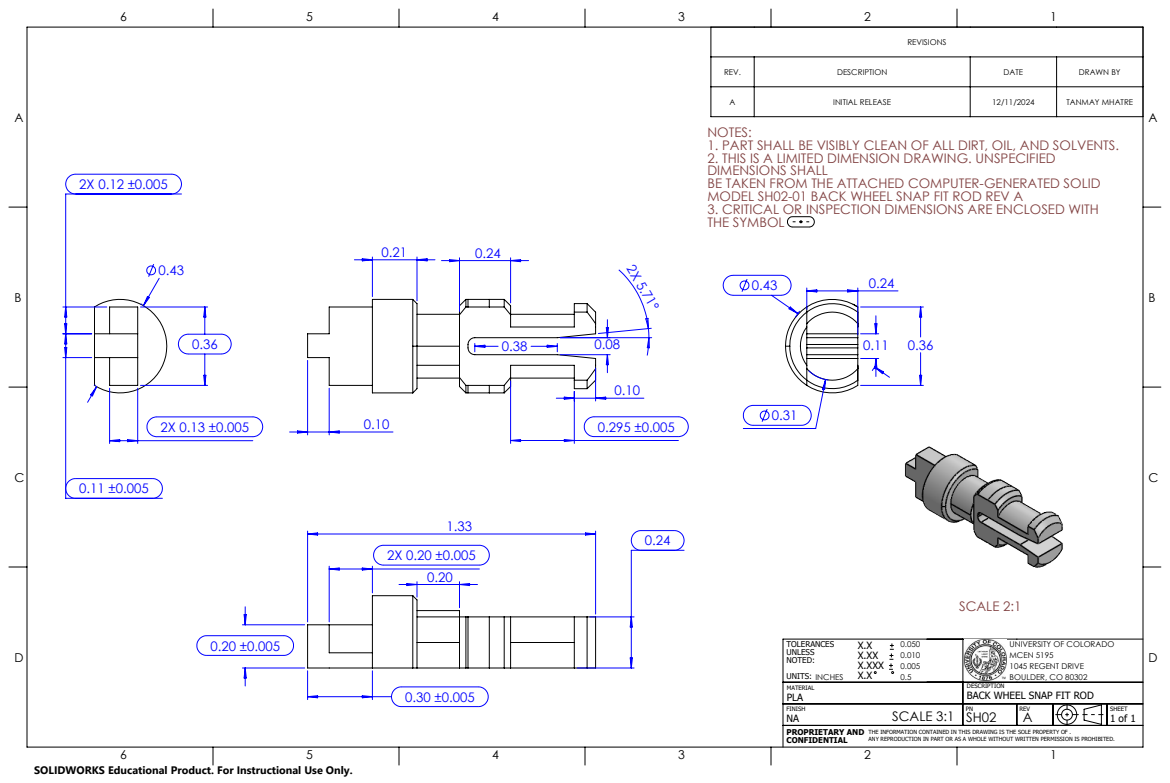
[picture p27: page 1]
SCALE 2:1; PROPRIETARY AND

REVISIONS

REV. | DESCRIPTION | DATE | DRAWN BY

A | INITIAL RELEASE | 12/11/2024 | TANMAY MHATRE

NOTES:
1. PART SHALL BE VISIBLY CLEAN OF ALL DIRT, OIL, AND SOLVENTS.
2. THIS IS A LIMITED DIMENSION DRAWING. UNSPECIFIED
DIMENSIONS SHALL
BE TAKEN FROM THE ATTACHED COMPUTER-GENERATED SOLID
MODEL SH02-01 BACK WHEEL SNAP FIT ROD REV A
3. CRITICAL OR INSPECTION DIMENSIONS ARE ENCLOSED WITH
THE SYMBOL

TOLERANCES X.X 0.050 UNLESS X.XX 0.010 NOTED: X.XXX 0.005 X.X UNITS: INCHES 0.5 | UNIVERSITY OF COLORADO MCEN 5195 1045 REGENT DRIVE BOULDER, CO 80302

MATERIAL PLA | DESCRIPTION BACK WHEEL SNAP FIT ROD
FINISH SCALE 3:1 NA | PN SH02 | REV A | SHEET 1 of 1

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

SOLIDWORKS Educational Product. For Instructional Use Only.

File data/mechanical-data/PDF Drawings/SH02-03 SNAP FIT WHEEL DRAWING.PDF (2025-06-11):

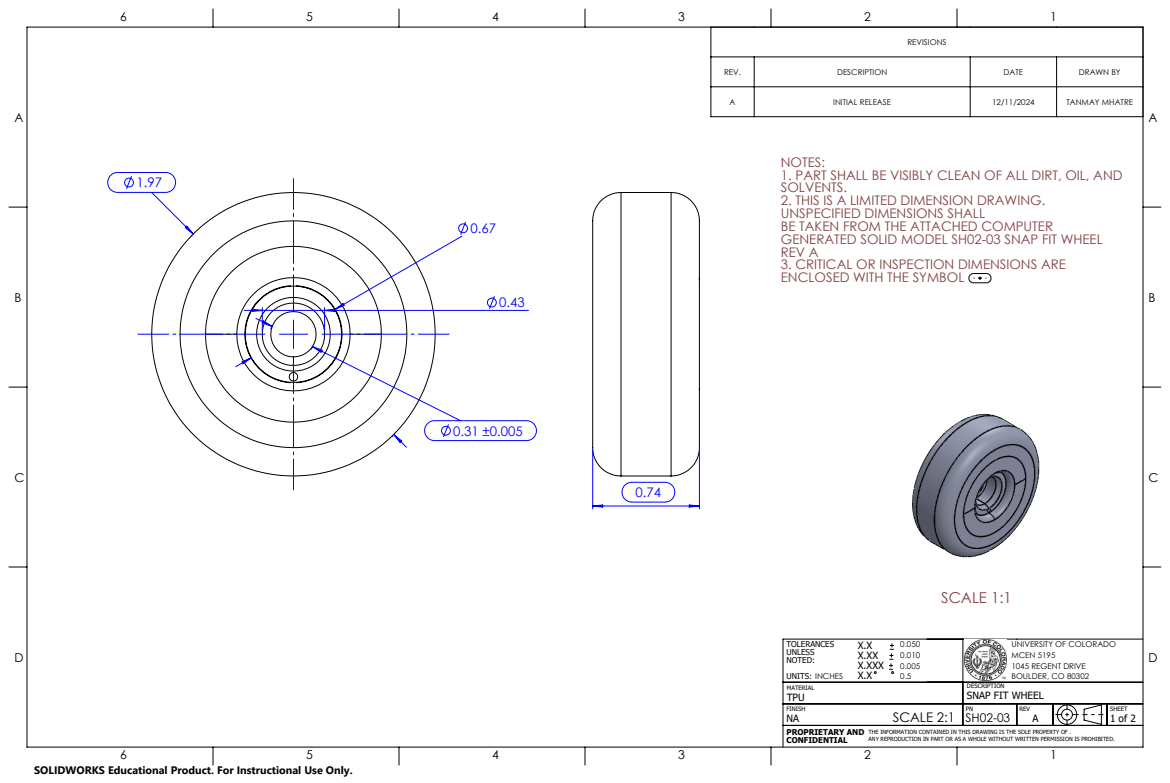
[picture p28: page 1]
SCALE 1:1; PROPRIETARY AND

REVISIONS

REV. | DESCRIPTION | DATE | DRAWN BY

A | INITIAL RELEASE | 12/11/2024 | TANMAY MHATRE

NOTES:
1. PART SHALL BE VISIBLY CLEAN OF ALL DIRT, OIL, AND
SOLVENTS.
2. THIS IS A LIMITED DIMENSION DRAWING.
UNSPECIFIED DIMENSIONS SHALL
BE TAKEN FROM THE ATTACHED COMPUTER
GENERATED SOLID MODEL SH02-03 SNAP FIT WHEEL
REV A
3. CRITICAL OR INSPECTION DIMENSIONS ARE
ENCLOSED WITH THE SYMBOL

TOLERANCES X.X 0.050 UNLESS X.XX 0.010 NOTED: X.XXX 0.005 X.X UNITS: INCHES 0.5 | UNIVERSITY OF COLORADO MCEN 5195 1045 REGENT DRIVE BOULDER, CO 80302

MATERIAL TPU | DESCRIPTION SNAP FIT WHEEL
FINISH SCALE 2:1 NA | PN SH02-03 | REV A | SHEET 1 of 2

THE INFORMATION CONTAINED IN THIS DRAWING IS THE SOLE PROPERTY OF .
ANY REPRODUCTION IN PART OR AS A WHOLE WITHOUT WRITTEN PERMISSION IS PROHIBITED.

SOLIDWORKS Educational Product. For Instructional Use Only.

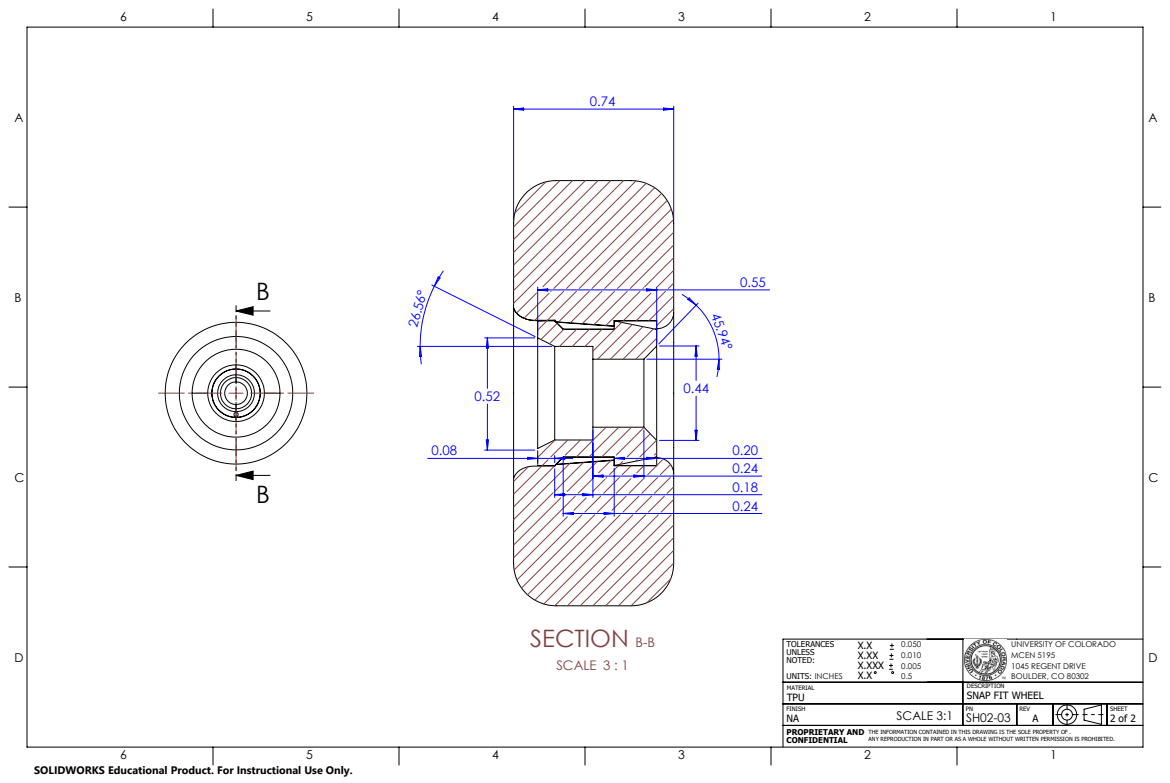
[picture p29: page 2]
SECTION B-B; SCALE 3 : 1; PROPRIETARY AND

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

MATERIAL TPU | DESCRIPTION SNAP FIT WHEEL
FINISH SCALE 3:1 NA | PN SH02-03 | REV A | SHEET 2 of 2

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

SOLIDWORKS Educational Product. For Instructional Use Only.

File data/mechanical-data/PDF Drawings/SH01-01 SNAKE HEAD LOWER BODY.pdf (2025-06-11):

A

6 | 5 | 4

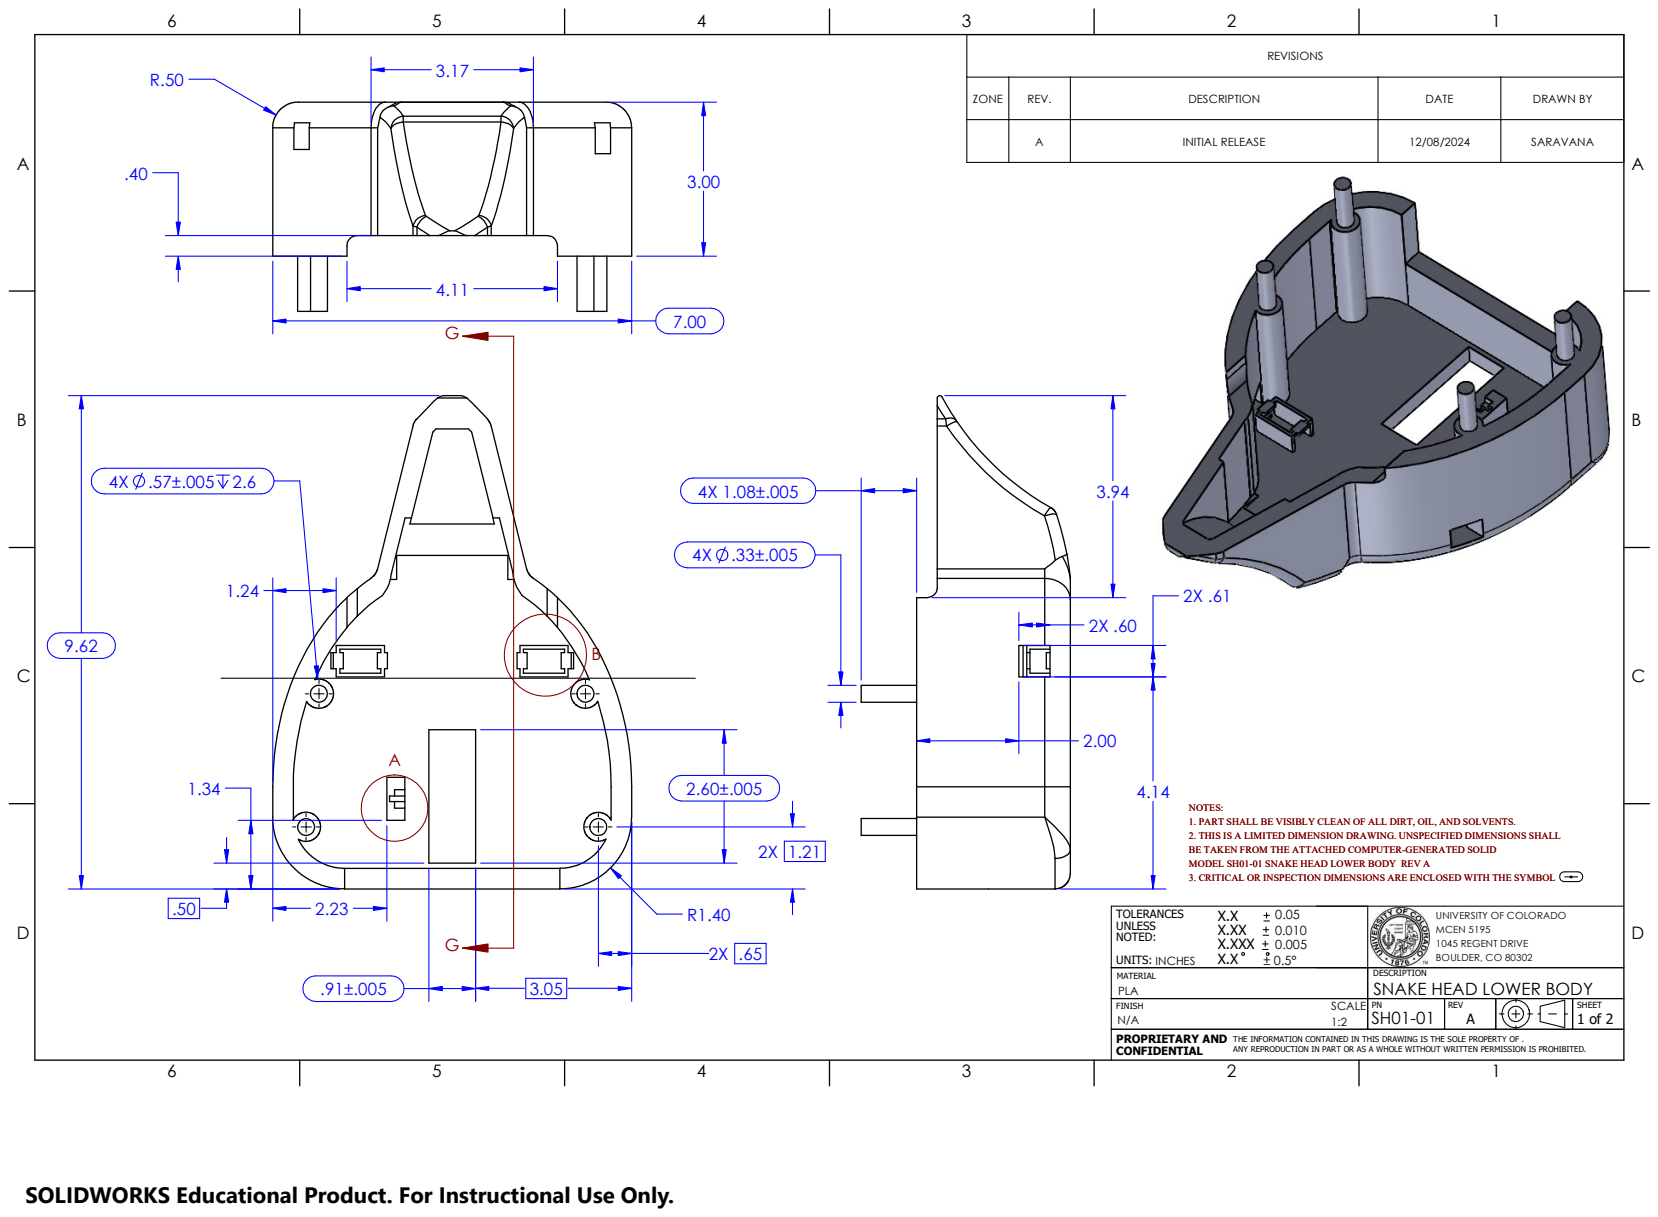
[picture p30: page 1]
PROPRIETARY AND CONFIDENTIAL

REVISIONS

ZONE | REV. | DESCRIPTION | DATE | DRAWN BY

A | INITIAL RELEASE | 12/08/2024 | SARAVANA

NOTES:
1. PART SHALL BE VISIBLY CLEAN OF ALL DIRT, OIL, AND SOLVENTS.
2. THIS IS A LIMITED DIMENSION DRAWING. UNSPECIFIED DIMENSIONS SHALL
BE TAKEN FROM THE ATTACHED COMPUTER-GENERATED SOLID
MODEL SH01-01 SNAKE HEAD LOWER BODY REV A
3. CRITICAL OR INSPECTION DIMENSIONS ARE ENCLOSED WITH THE SYMBOL

TOLERANCES X.X 0.05 UNLESS X.XX 0.010 NOTED: X.XXX 0.005 UNITS: X.X ± 0.5° INCHES | UNIVERSITY OF COLORADO MCEN 5195 1045 REGENT DRIVE BOULDER, CO 80302

MATERIAL PLA | DESCRIPTION SNAKE HEAD LOWER BODY

SCALE FINISH N/A 1:2 | PN SH01-01 | REV A 1 of 2 | SHEET

THE INFORMATION CONTAINED IN THIS DRAWING IS THE SOLE PROPERTY OF .
ANY REPRODUCTION IN PART OR AS A WHOLE WITHOUT WRITTEN PERMISSION IS PROHIBITED.

SOLIDWORKS Educational Product. For Instructional Use Only.

0.2
2X .20±.005

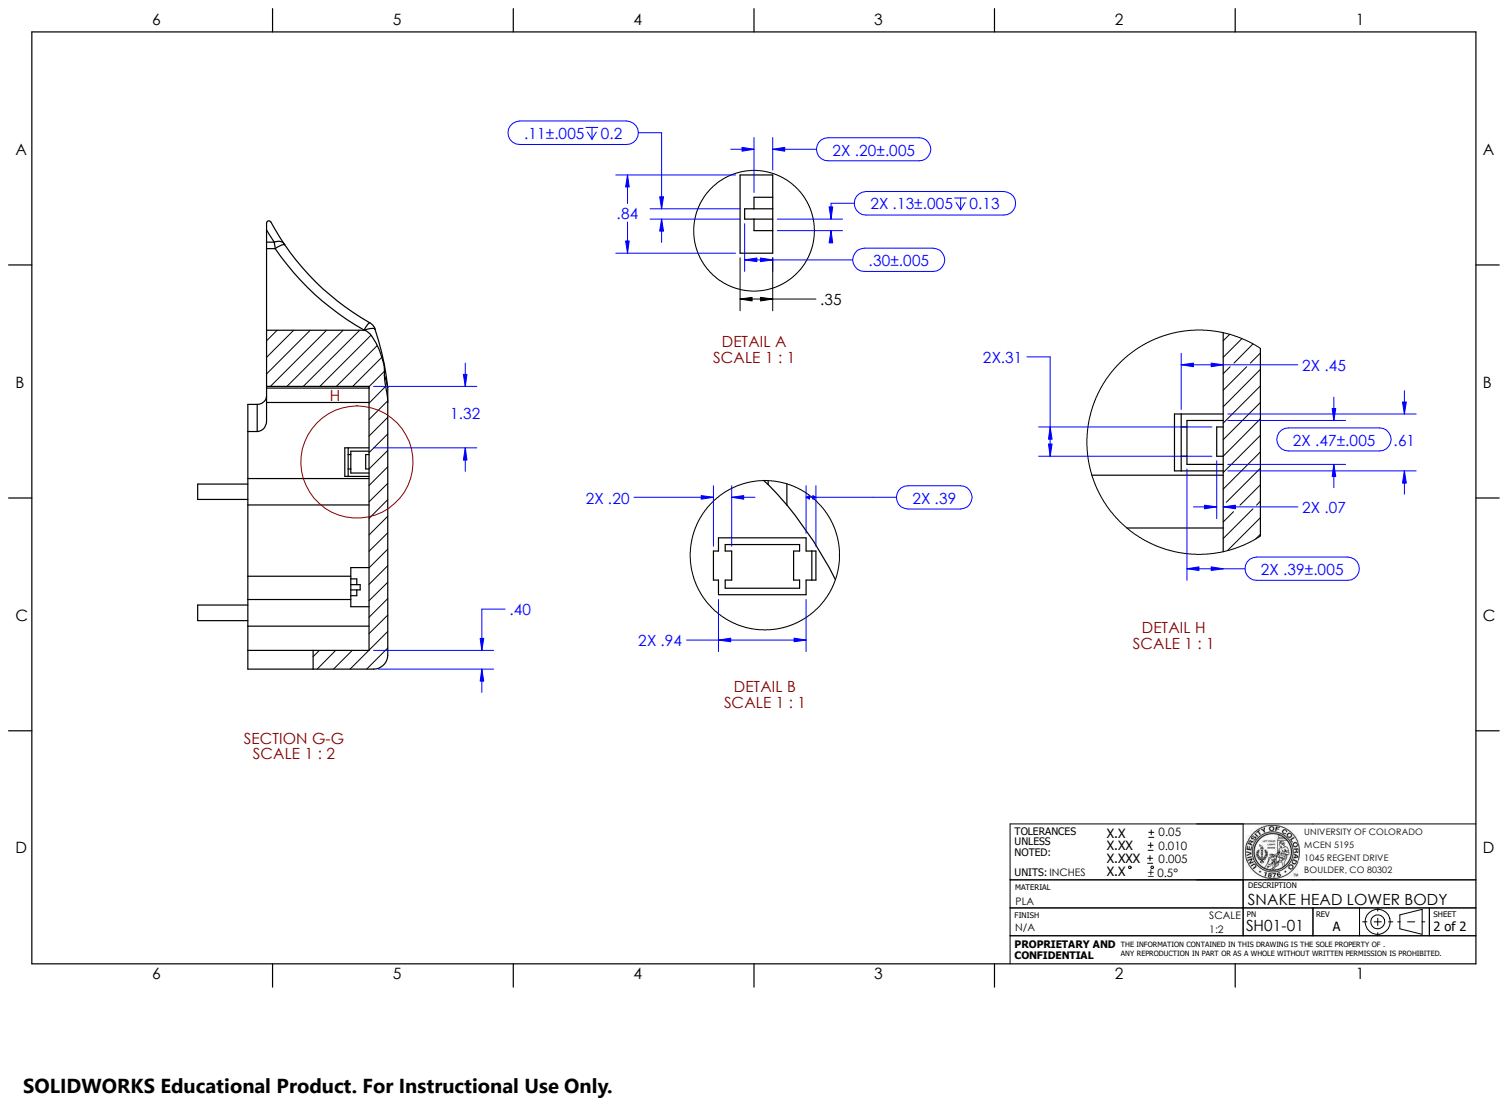
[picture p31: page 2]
DETAIL B SCALE 1 : 1; DETAIL A SCALE 1 : 1; PROPRIETARY AND CONFIDENTIAL; SECTION G-G SCALE 1 : 2; DETAIL H SCALE 1 : 1

TOLERANCES X.X 0.05 UNLESS X.XX 0.010 NOTED: X.XXX 0.005 UNITS: INCHES X.X ± 0.5° | UNIVERSITY OF COLORADO MCEN 5195 1045 REGENT DRIVE BOULDER, CO 80302

MATERIAL PLA | DESCRIPTION SNAKE HEAD LOWER BODY

SCALE FINISH N/A 1:2 | PN SH01-01 | REV A | SHEET 2 of 2

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

SOLIDWORKS Educational Product. For Instructional Use Only.

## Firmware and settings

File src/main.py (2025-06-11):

import datetime
import cv2
import sys
import numpy as np
import numpy.typing as npt
import time,board,busio
import adafruit_mlx90640
import matplotlib.image
import RPi.GPIO as GPIO
from libcamera import controls

from PIL import Image
from scipy.ndimage import center_of_mass
from picamera2 import Picamera2
from apriltag import apriltag

# pwm control for motors
PWMA = None # left motor
PWMB = None # right motor
# motor driver pins
PWMA_PIN = 12 # GPIO 12
AIN2_PIN = 15 # GPIO 15
AIN1_PIN = 18 # GPIO 18
STBY_PIN = 23 # GPIO 23
BIN1_PIN = 24 # GPIO 24
BIN2_PIN = 25 # GPIO 25
PWMB_PIN = 13 # GPIO 13

# TODO uncomment for Julianne testing 
i2c: busio.I2C = None
mlx: adafruit_mlx90640.MLX90640 = None
# i2c = None
# mlx = None

isdebug: bool = "-d" in sys.argv or "--debug" in sys.argv
islogdata: bool = "-ld" in sys.argv or "--log-data" in sys.argv
print_body_temp: bool = "--body-temp" in sys.argv

# thermal camera constants
THERMAL_WIDTH = 32
THERMAL_HEIGHT = 24

THERMAL_MIN = -40 # °C
THERMAL_MAX = 100 # °C

BODY_TEMP_C = 35.2
BODY_TEMP_TOLERANCE = 5

frame_height = None
frame_width = None

# gobal vars for saving video and log data
logdata_prefix = f"{datetime.datetime.now().isoformat()}".replace(":", "-")

# width,height is the two frames concatted together one scaled
video_file = logdata_prefix + ".avi"
fourcc = cv2.VideoWriter_fourcc(*"XVID")
video = None

# headers for logdata
logdata = [[
    "time_ms",
    "visual_on",
    "thermal_on",
    "distance_v",
    "heading_angle_v",
    "heading_angle_t",
    "centroid_v_x",
    "centroid_v_y",
    "centroid_t_x",
    "centroid_t_y",
]]

# pin for controlling program execution
RUN_PIN = 22 # GPIO 22

# pins for toggling thermal or visual sensing
THERMAL_ON = not "--no-thermal" in sys.argv
VISUAL_ON = not "--no-visual" in sys.argv

def is_run_enabled() -> bool:
    """Read pin to determine if the control loop should be ran or halted."""
    res = GPIO.input(RUN_PIN)
    return res == 1

def save_frame_to_video(frame, width, height):
    """Same `frame` to globally-stored video for the session"""
    global video
    fps = 2
    frame = cv2.cvtColor(frame, cv2.COLOR_BGR2GRAY)
    frame = cv2.cvtColor(frame, cv2.COLOR_GRAY2BGR)

    if video is None:
        video = cv2.VideoWriter(video_file, fourcc, fps, (width, height))

    if video.isOpened():
        video.write(frame)
        print("[INFO] wrote frame")
    else:
        raise RuntimeError("videowriter not opened!")

def setup_motor_driver():
    """Set up the motor driver."""
    global PWMA, PWMB
    GPIO.cleanup()
    GPIO.setmode(GPIO.BCM)
    GPIO.setup(PWMA_PIN, GPIO.OUT)
    GPIO.setup(AIN2_PIN, GPIO.OUT)
    GPIO.setup(AIN1_PIN, GPIO.OUT)
    GPIO.setup(STBY_PIN, GPIO.OUT)
    GPIO.setup(BIN1_PIN, GPIO.OUT)
    GPIO.setup(BIN2_PIN, GPIO.OUT)
    GPIO.setup(PWMB_PIN, GPIO.OUT)
    PWMA = GPIO.PWM(PWMA_PIN, 1000)
    PWMB = GPIO.PWM(PWMB_PIN, 1000)
    GPIO.output(STBY_PIN, GPIO.HIGH)
    PWMA.start(0)
    PWMB.start(0)
    # note: these must be pulled down externally
    GPIO.setup(RUN_PIN, GPIO.IN, pull_up_down=GPIO.PUD_DOWN)

def shut_off_motors():
    GPIO.output(STBY_PIN, GPIO.LOW)

def drive_right_motor(speed: int, direction: str):
    global PWMA
    if speed >= 0 and speed <= 100:
        PWMA.ChangeDutyCycle(speed)

    if direction == "forward":
        GPIO.output(AIN1_PIN, GPIO.LOW)
        GPIO.output(AIN2_PIN, GPIO.HIGH)
    elif direction == "backward":
        GPIO.output(AIN1_PIN, GPIO.HIGH)
        GPIO.output(AIN2_PIN, GPIO.LOW)
    else:
        raise ValueError("did not get 'forward' or 'backward'")

def drive_left_motor(speed: int, direction: str):
    global PWMB
    if speed >= 0 and speed <= 100:
        PWMB.ChangeDutyCycle(speed)

    if direction == "forward":
        GPIO.output(BIN1_PIN, GPIO.HIGH)
        GPIO.output(BIN2_PIN, GPIO.LOW)
    elif direction == "backward":
        GPIO.output(BIN1_PIN, GPIO.LOW)
        GPIO.output(BIN2_PIN, GPIO.HIGH)
    else:
        raise ValueError("did not get 'forward' or 'backward'")

def setup_thermal_camera():
    """Set up the thermal camera via I2C."""
    global i2c, mlx
    i2c = busio.I2C(board.SCL, board.SDA, frequency=800e3)
    mlx = adafruit_mlx90640.MLX90640(i2c)
    print("MLX address detected on I2C", [hex(i) for i in mlx.serial_number])

    # note: can also use REFRESH_16_HZ, REFRESH_8_HZ, REFRESH_4_HZ, REFRESH_2_HZ, and others
    # (see source for more)
    mlx.refresh_rate = adafruit_mlx90640.RefreshRate.REFRESH_4_HZ

def setup_visual_camera():
    """Set up the Raspberry Pi rpicam."""
    picam2 = Picamera2()
    config = picam2.create_video_configuration()
    picam2.configure(config)
    picam2.start()

    # allow picam to start up...
    time.sleep(1)

    # Get the default frame width and height
    global frame_width, frame_height
    frame_width = config["main"]["size"][0]
    frame_height = config["main"]["size"][1]

    if isdebug:
        print(f"frame_width, frame_height: {frame_width}, {frame_height}")
        print(f"exposure: {picam2.camera_controls['ExposureTime']}")
        print(f"brightness: {picam2.camera_controls['Brightness']}")

    return picam2

def process_thermal_frame(buf: npt.ArrayLike):
    global mlx, thermal_img
    try:
        mlx.getFrame(buf)
    except ValueError:
        # apparently we're supposed to ignore these
        return
    mat = np.reshape(buf, (THERMAL_HEIGHT, THERMAL_WIDTH))
    # flip the image across left-right so that its view is authentic POV
    mat = np.fliplr(mat)
    return mat

def process_april_tags(r, frame_width, frame_height):
    # get coordinates of corners
    lb = r['lb-rb-rt-lt'][0]
    rb = r['lb-rb-rt-lt'][1]
    rt = r['lb-rb-rt-lt'][2]
    lt = r['lb-rb-rt-lt'][3]

    centroid =(int(r['center'][1]), int(r['center'][0])) # the centroid reads out x as y in camera frame
    image_shape = (frame_height, frame_width) # 1080x1920 in pixel coordaintes 
    camera_fov_y = 62.2

    # NOT ROTATION INVARIANT YET
    april_tag_length_pixels = np.linalg.norm(lt - rb)

    distance, heading_angle = calculate_heading_angle(centroid, image_shape, camera_fov_y, april_tag_length_pixels)

    if isdebug:
        print(f"[INFO] April tag is at {(int(r['center'][1]), int(r['center'][0]))}")
        print("[INFO] Pixel  length:", april_tag_length_pixels)
        print(f"[INFO] The robot needs to turn {heading_angle:.2f} degrees to face the centroid.")
        print(f"[INFO] Distance {distance:.2f} in m.")

    return distance, heading_angle

def find_centroid_of_hot_area(temperature_array, threshold, tolerance):
    """
    Finds the centroid of the hot area in a temperature array.
    """
    # binary mask for the hot areas (areas above the threshold)
    hot_mask = (temperature_array - tolerance > threshold)
    if np.all(hot_mask == False):
        return (None, None)
    # find centroid using the center_of_mass function from scipy
    centroid = center_of_mass(hot_mask)
    if isdebug:
        print(f"[INFO] thermal centroid: {(int(centroid[0]), int(centroid[1]))}")
    return (int(centroid[0]), int(centroid[1]))

def calculate_heading_angle(centroid, image_shape, camera_fov_y, april_tag_length_pixels=None):
    """
    Calculate the heading angle to turn the robot towards the centroid in the image.
    
    Parameters:
    - centroid: (cx, cy) - the centroid coordinates of the hot area.
    - image_shape: (height, width) - the dimensions of the image (height, width).
    - camera_fov_x: float - the horizontal field of view of the camera in degrees.
    
    Returns:
    - heading_angle: float - the angle (in degrees) the robot needs to turn to face the centroid.
    """

    # NOTE REMEMBER THAT X IS UP DOWN AND Y IS SIDE IN CAMERA SPACE
    
    # center of the image (cx_center, cy_center)
    cx_center, cy_center = image_shape[0] // 2, image_shape[1] // 2  # image shape: (height, width)
    
    # displacement from the center to the centroid
    delta_y = centroid[1] - cy_center  # horizontal displacement in pixels
    
    # angle per pixel
    angle_per_pixel = camera_fov_y / image_shape[1]  # field of view in degrees per pixel
    
    # heading angle in degrees (relative to the center of the image)
    heading_angle = delta_y * angle_per_pixel

    # calculate depth if April tag is detected

    if april_tag_length_pixels != None:
        focal_length = frame_width 
        tag_size = 3/100 #3 cm
        distance = (tag_size * focal_length) / april_tag_length_pixels  # distance in meters
    else:
        distance = None # thermal sensing
    
    return distance, heading_angle

def end_of_sequence():
    """Run tasks for the end of the sequence."""
    global video
    shut_off_motors()
    video.release()
    video = None
    if islogdata:
        with open(logdata_prefix + ".csv", "w") as f:
            for logitem in logdata:
                f.write(",".join(map(str, logitem)))
                f.write("\n")
        print(f"[INFO] saved logdata to {logdata_prefix}.csv")

def control_loop():
    ## 0: SETUP SENSORS ##
    setup_motor_driver()
    # Visual Camera
    global frame_height, frame_width
    picam2 = setup_visual_camera()

    # Thermal camera
    global i2c, mlx, isdebug
    cam_t = setup_thermal_camera() # FIX ME how to return data?
        
    # TODO sync loop to refresh rate of slowest sensor

    distance_v = None
    heading_angle_v = None
    heading_angle_t = None
    centroid_v: tuple = (None, None)
    centroid_t: tuple = (None, None)
    visual_frame = None
    thermal_frame = None
    
    while True: 
        ## 1: DATA PROCESSING FROM SENSORS ##
        # Visual Camera
        visual_frame = picam2.capture_array("main")
        if VISUAL_ON:
            visual_greyscale = cv2.cvtColor(visual_frame, cv2.COLOR_BGR2GRAY)

            if isdebug:
                print("[INFO] detecting AprilTags...")

            detector = apriltag("tag36h11")
            results = detector.detect(visual_greyscale) # This returns the number of april tags detected

            if len(results) == 0:
                heading_angle_v = None
                distance_v = None
            else:
                # TODO - for now assume one april tag
                print("[INFO] April tag detected")
                r = results[0]
                centroid_v = (r["center"][0], r["center"][1])
                distance_v, heading_angle_v = process_april_tags(r, frame_width, frame_height)

            if isdebug:
                print("[INFO] {} total AprilTags detected".format(len(results)))
                for r in results:
                    # extract the bounding box (x, y)-coordinates for the AprilTag
                    # and convert each of the (x, y)-coordinate pairs to integers
                    lb = r['lb-rb-rt-lt'][0].astype(int)
                    rb = r['lb-rb-rt-lt'][1].astype(int)
                    rt = r['lb-rb-rt-lt'][2].astype(int)
                    lt = r['lb-rb-rt-lt'][3].astype(int)

                    # draw the bounding box of the AprilTag detection
                    cv2.line(visual_frame, lt, rt, (0, 255, 0), 2)
                    cv2.line(visual_frame, rt, rb, (0, 255, 0), 2)
                    cv2.line(visual_frame, rb, lb, (0, 255, 0), 2)
                    cv2.line(visual_frame, lb, lt, (0, 255, 0), 2)
                    # draw the center (x, y)-coordinates of the AprilTag
                    (cX, cY) = (int(r['center'][0]), int(r['center'][1]))
                    cv2.circle(visual_frame, (cX, cY), 5, (0, 0, 255), -1)
                    # draw the tag family on the image
                    # tagFamily = r.tag_family.decode("utf-8")
                    # cv2.putText(visual_frame, tagFamily, (ptA[0], ptA[1] - 15),
                    #    cv2.FONT_HERSHEY_SIMPLEX, 0.5, (0, 255, 0), 2)
                    # print("[INFO] tag family: {}".format(tagFamily))
                    # show the output image after AprilTag detection
            
        # Thermal Camera
        thermal_buf = np.array([0] * 768)
        thermal_frame_temp = process_thermal_frame(thermal_buf)
        thermal_frame = thermal_frame_temp if thermal_frame_temp is not None else thermal_frame

        if THERMAL_ON:
            threshold_temperature = 40
            tolerance = BODY_TEMP_TOLERANCE
            # TODO might need to debug compatibility of thermal frame - 
            centroid_t = find_centroid_of_hot_area(thermal_frame, threshold_temperature, tolerance)
            
            image_shape = (THERMAL_HEIGHT, THERMAL_WIDTH)
            camera_fov_y = 110  # Horizontal FOV of the camera 

            # only calculate heading angle if centroid was found
            if centroid_t[0] is None or centroid_t[1] is None:
                heading_angle_t = None
            else:
                # Calculate the heading angle
                _, heading_angle_t = calculate_heading_angle(centroid_t, image_shape, camera_fov_y)
                print(f"[THERMAL] The robot needs to turn {heading_angle_t:.2f} degrees to face the centroid.")

        # scale the image to show regardless of if we're finding the centroid
        if isdebug:
            thermal_frame = ((thermal_frame - THERMAL_MIN) / THERMAL_MAX * 255).astype(int)
            thermal_frame = np.array(thermal_frame, dtype=np.uint8)
            # create scale to give visual and thermal images same width
            scale = int(frame_width / thermal_frame.shape[1])
            thermal_frame = cv2.resize(
                    thermal_frame,
                    (thermal_frame.shape[1] * scale, thermal_frame.shape[0] * scale),
                    interpolation=cv2.INTER_NEAREST,
            )
            thermal_frame = np.stack(
                    [thermal_frame] * 4,
                    axis = -1,
            )
            # if we're finding the centroid, display it
            if THERMAL_ON:
                # add the centroid to the scaled image
                if centroid_t[0] is not None and centroid_t[1] is not None:
                    centroid_t = (centroid_t[0] * scale, centroid_t[1] * scale)
                    cv2.circle(thermal_frame, (centroid_t[1], centroid_t[0]), 5, (0, 0, 255), -1)

        if isdebug:
            im_to_show = np.vstack((thermal_frame, visual_frame))
            save_frame_to_video(
                frame=im_to_show,
                width=im_to_show.shape[1],
                height=im_to_show.shape[0],
            )
            cv2.imshow("image", im_to_show)

        ## 2: ACTUATE MOTORS BASED ON SENSOR DATA ##
        # TODO turn towards heading angles of thermal camera and vision camera

        use_thermal: bool = THERMAL_ON and heading_angle_t is not None
        use_visual: bool = VISUAL_ON and heading_angle_v is not None

        if islogdata:
            logdata.append([
                time.time(),
                VISUAL_ON,
                THERMAL_ON,
                distance_v,
                heading_angle_v,
                heading_angle_t,
                centroid_v[0],
                centroid_v[1],
                centroid_t[0],
                centroid_t[1],
            ])

        if use_thermal and use_visual:
            avg_turn_angle = (heading_angle_v + heading_angle_t) / 2
        elif use_visual:
            avg_turn_angle = heading_angle_v 
        elif use_thermal:
            avg_turn_angle = heading_angle_t
        else:
            avg_turn_angle = None

        print(f"[INFO] average turning angle: {avg_turn_angle}")

        if avg_turn_angle is None:
            drive_right_motor(0, "forward")
            drive_left_motor(0, "forward")
        else:
            # duty cycle value is twice the turn angle
            # and gets clipped in [0,100]
            # duty_cycle_value = max(0, min(100, int(abs(avg_turn_angle * 2))))

            if avg_turn_angle > 1: # turn right
                if isdebug:
                    print("[INFO] turn right")
                drive_right_motor(10, "backward")
                drive_left_motor(10, "forward")
            elif avg_turn_angle < -1: # turn left
                if isdebug:
                    print("[INFO] turn left")
                drive_right_motor(10, "forward")
                drive_left_motor(10, "backward")
            else:
                drive_right_motor(100, "forward")
                drive_left_motor(100, "forward")



        ## 3: BREAK CONDIITON ##
        if cv2.waitKey(1) == ord('q'):
            # if 'q' is pressed, kill it.
            end_of_sequence()
            GPIO.cleanup()
            cv2.destroyAllWindows()
            exit(0)
        
        if not is_run_enabled():
            # if the RUN_PIN is disconnected, wait until it is reconnected to
            # start again.
            end_of_sequence()

            while not is_run_enabled():
                if cv2.waitKey(1) == ord('q'):
                    # if 'q' is pressed, kill it.
                    GPIO.cleanup()
                    cv2.destroyAllWindows()
                    exit(0)
                time.sleep(1)

            # rename logdata prefix to be new time
            global logdata_prefix
            logdata_prefix = f"{datetime.datetime.now().isoformat()}".replace(":", "-")
        

if __name__ == "__main__":
    control_loop()

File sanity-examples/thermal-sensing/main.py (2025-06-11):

import sys
import cv2 as cv
import numpy as np
import numpy.typing as npt
import time,board,busio
import adafruit_mlx90640
import matplotlib.image

i2c: busio.I2C = None
mlx: adafruit_mlx90640.MLX90640 = None

isdebug: bool = "-d" in sys.argv or "--debug" in sys.argv
print_body_temp: bool = "--body-temp" in sys.argv

THERMAL_WIDTH = 24
THERMAL_HEIGHT = 32

BODY_TEMP_C = 35.2
BODY_TEMP_TOLERANCE = 5


def setup_thermal_camera():
    """Set up the thermal camera via I2C."""
    global i2c, mlx
    i2c = busio.I2C(board.SCL, board.SDA, frequency=800e3)
    mlx = adafruit_mlx90640.MLX90640(i2c)
    print("MLX address detected on I2C", [hex(i) for i in mlx.serial_number])

    # note: can also use REFRESH_16_HZ, REFRESH_8_HZ, REFRESH_4_HZ, REFRESH_2_HZ, and others
    # (see source for more)
    mlx.refresh_rate = adafruit_mlx90640.RefreshRate.REFRESH_4_HZ


def setup_visual_camera():
    """Set up the visual camera."""
    # FIXME
    pass


def print_normalized_matrix(w: int, h: int, mat: npt.ArrayLike):
    """Print out an ascii representation of a matrix."""
    min_val = mat.min()
    max_val = mat.max()
    for i in range(w):
        for j in range(h):
            val = mat[i,j]
            disp = (" .'`^\",:;Il!i><~+_-?][}{1)(|\\/tfjrxnuvczXYUJCLQ0OZmwqpdbkhao*#M&W8%B@$")[round((val - min_val) / (max_val - min_val) * 69)]
            print(disp, end=" ")
        print()
    print()


def process_thermal_frame(ind: int, buf: npt.ArrayLike):
    global mlx, thermal_img
    try:
        mlx.getFrame(buf)
    except ValueError:
        # apparently we're supposed to ignore these
        return
    mat = np.reshape(buf, (THERMAL_WIDTH, THERMAL_HEIGHT))
    if print_body_temp:
        # calculate mask of values that fall within what we predict a body temperature to be
        body_temp_mask = cv.inRange(
            mat,
            BODY_TEMP_C - BODY_TEMP_TOLERANCE,
            BODY_TEMP_C + BODY_TEMP_TOLERANCE,
        )
        print_normalized_matrix(THERMAL_WIDTH, THERMAL_HEIGHT, body_temp_mask)
    if isdebug:
        print_normalized_matrix(THERMAL_WIDTH, THERMAL_HEIGHT, mat)
        fname = f"thermal-data-{ind:03}.png"
        result = cv.imwrite(fname, mat)
        print(f"image saving result: {fname}", result)


def process_visual_frame():
    pass


def main():
    global i2c, mlx, isdebug

    setup_thermal_camera()
    setup_visual_camera()
    thermal_buf = np.array([0] * 768)
    i = 0
    while True:
        process_thermal_frame(i, thermal_buf)
        process_visual_frame()
        i += 1
    

if __name__ == "__main__":
    main()
